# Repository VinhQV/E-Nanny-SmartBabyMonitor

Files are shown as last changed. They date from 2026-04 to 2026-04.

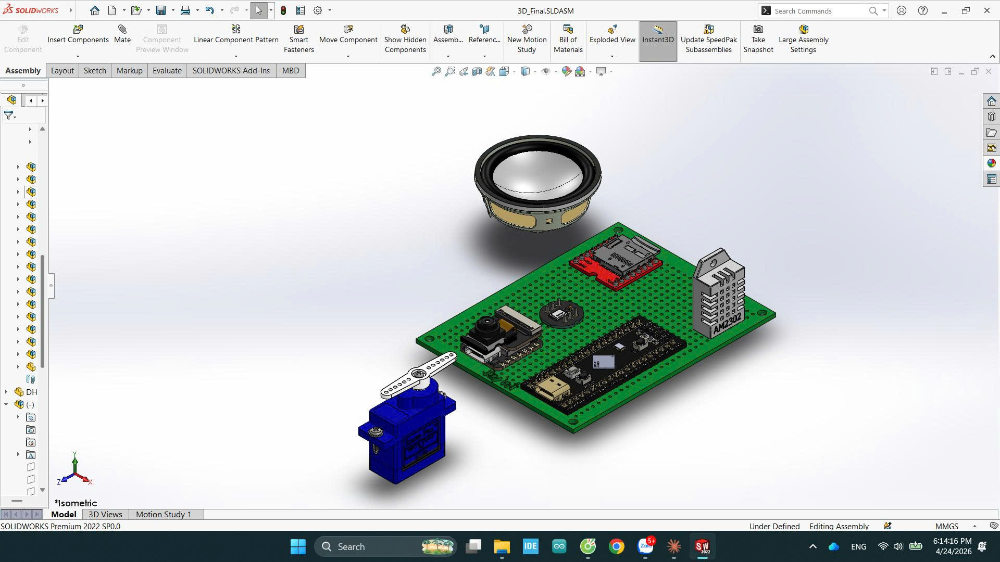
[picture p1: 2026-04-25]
media/images/hardware/3dBoardjpg.jpg

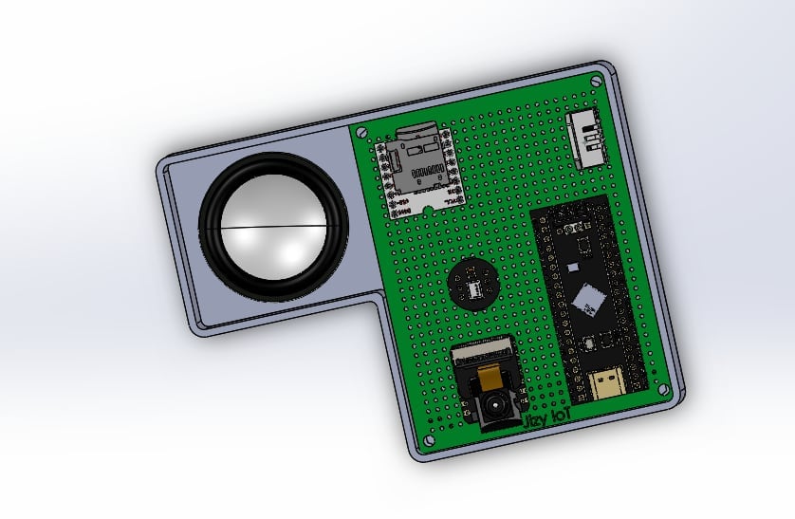
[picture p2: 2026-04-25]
media/images/hardware/fullLinhKien.jpg

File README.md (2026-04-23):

<div align="center">

# 🍼 E-Nanny: Smart Baby Monitor

**An intelligent IoT baby monitoring system built with STM32F401 + ESP32S3**







> A real-time embedded system that **detects baby crying using on-device AI**, monitors environment, soothes the baby automatically with lullabies and cradle rocking — all viewable from a live IoT dashboard.

---

System Demo
<!-- Replace with your actual demo photo/GIF -->

</div>

---

## ✨ Features

- 🤖 **On-Device AI Cry Detection** — TinyML model running on ESP32S3, classifies baby cry in real-time without sending audio to the cloud
- 📷 **Live Camera Feed** — OV2640 camera streams video via ESP32S3 for remote monitoring
- 🌡️ **Environment Sensing** — DHT22 measures temperature & humidity inside the cradle
- 🎵 **Auto Lullaby Playback** — DFPlayer Mini plays soothing music when crying is detected
- 🔄 **Cradle Auto-Rocking** — Servo SG90 gently rocks the cradle in response to baby state
- 📊 **IoT Dashboard** — ThingsBoard dashboard displays real-time sensor data & baby status
- ⚡ **Non-blocking Firmware** — STM32 firmware uses HAL_GetTick() + State Machine (no HAL_Delay)
- 🔗 **Dual-MCU Architecture** — STM32 handles real-time peripherals; ESP32S3 handles AI + networking

---

## 🏗️ System Architecture

```
┌─────────────────────────────────┐         ┌──────────────────────────────────────┐
│     STM32F401CCU6 (Core MCU)    │         │        ESP32S3 (IoT Gateway)         │
│                                 │         │                                      │
│  ┌──────────┐  ┌─────────────┐  │  UART   │  ┌──────────┐   ┌────────────────┐  │
│  │  DHT22   │  │ DFPlayer    │  │◄───────►│  │ AI Engine│   │ Camera Module  │  │
│  │ Temp/Hum │  │ (Lullaby)   │  │         │  │(Cry Detect│   │ (OV2640)       │  │
│  └──────────┘  └─────────────┘  │         │  └──────────┘   └────────────────┘  │
│                                 │         │                                      │
│  ┌──────────┐  ┌─────────────┐  │         │  ┌──────────┐   ┌────────────────┐  │
│  │ Servo    │  │  State      │  │         │  │ Audio    │   │ Cloud Client   │  │
│  │ SG90     │  │  Machine    │  │         │  │ Mic      │   │ (MQTT/WiFi)    │  │
│  │(Rocking) │  │ (Non-block) │  │         │  └──────────┘   └───────┬────────┘  │
│  └──────────┘  └─────────────┘  │         │                         │           │
└─────────────────────────────────┘         └─────────────────────────┼───────────┘
                                                                       │ MQTT
                                                                       ▼
                                                          ┌────────────────────┐
                                                          │   ThingsBoard IoT  │
                                                          │   Cloud Dashboard  │
                                                          │  (Temp/Hum/Status) │
                                                          └────────────────────┘
```

### Communication Protocol (STM32 ↔ ESP32)

| From | To | Protocol | Data |
|---|----|---|---|
| STM32 | ESP32S3 | UART 115200 baud | Temperature, Humidity (framed packet) |
| ESP32S3 | STM32 | UART 115200 baud | Commands: play music (0x01), rock cradle (0x04) |
| ESP32S3 | ThingsBoard | MQTT over WiFi | Telemetry + Baby Status string |
| ESP32S3 | OV2640 | DVP + I2C | Camera frame capture |

---

## 📦 Hardware Bill of Materials

| Component | Role | Interface | Notes |
|---|---|---|---|
| STM32F401CCU6 | Main MCU | — | ARM Cortex-M4, 84 MHz, 256KB Flash |
| Seeed XIAO ESP32S3 Sense | AI + IoT Gateway | UART | Built-in OV2640 camera + INMP441 mic |
| DHT22 (AM2302) | Temp & Humidity Sensor | 1-Wire GPIO | ±0.5°C / ±2% RH accuracy |
| DFPlayer Mini | MP3/WAV Player | UART 9600 baud | MicroSD card, 3.2W amplifier |
| Servo SG90 | Cradle Rocking Motor | PWM (TIM) | 4.8–6V, 180° rotation |

---

## 📁 Project Structure

```
E-Nanny-SmartBabyMonitor/
│
├── 📁 stm32-firmware/              # STM32CubeIDE Project (STM32F401CCU6)
│   └── Core/
│       ├── App/
│       │   ├── ChuongTrinhChinh.c  # Main application loop (non-blocking)
│       │   └── Libraries/
│       │       ├── DHT22/          # DHT22 driver (HAL_GetTick based)
│       │       └── DFPlayer/       # DFPlayer Mini UART driver
│       └── Src/
│           └── main.c              # HAL init + peripheral config (CubeMX generated)
│
├── 📁 esp32-firmware/              # PlatformIO Project (ESP32S3)
│   └── src/
│       ├── main.cpp                # Setup + main loop
│       ├── AiEngine.cpp/h          # TinyML cry detection inference
│       ├── AudioMic.cpp/h          # I2S microphone sampling (INMP441)
│       ├── CameraModule.cpp/h      # OV2640 init + frame capture
│       ├── CloudClient.cpp/h       # WiFi + MQTT (ThingsBoard)
│       └── Stm32Controller.cpp/h   # UART bridge to STM32
│
└── 📁 docs/
    ├── images/                     # Photos, screenshots, demo GIF
    └── hardware/                   # Wiring diagrams
```

---

## 🔧 Getting Started

### Prerequisites

**STM32 Firmware:**
- [STM32CubeIDE](https://www.st.com/en/development-tools/stm32cubeide.html) v1.13+
- ST-Link V2 programmer

**ESP32S3 Firmware:**
- [Visual Studio Code](https://code.visualstudio.com/) + [PlatformIO](https://platformio.org/) extension

### 1. Clone the Repository

```bash
git clone https://github.com/YOUR_USERNAME/E-Nanny-SmartBabyMonitor.git
cd E-Nanny-SmartBabyMonitor
```

### 2. Configure WiFi & ThingsBoard credentials

Edit `esp32-firmware/src/CloudClient.cpp`:

```cpp
const char* ssid     = "YOUR_WIFI_SSID";
const char* password = "YOUR_WIFI_PASSWORD";
const char* tb_token = "YOUR_THINGSBOARD_DEVICE_TOKEN";
```

> ⚠️ **Never commit real credentials to Git!** Use a `secrets.h` file that is listed in `.gitignore`.

### 3. Flash STM32 Firmware

1. Open `stm32-firmware/` folder in **STM32CubeIDE**
2. Connect ST-Link V2 to the STM32F401CCU6 board
3. `Project → Build All` → `Run → Debug`

### 4. Flash ESP32S3 Firmware

```bash
cd esp32-firmware
pio run --target upload
pio device monitor   # View serial output at 115200 baud
```

---

## 💡 Software Design Highlights

### Non-Blocking STM32 Architecture
The STM32 firmware uses a **State Machine + HAL_GetTick()** pattern — no `HAL_Delay()` blocking calls anywhere. All sensors and actuators are handled concurrently in a cooperative scheduling loop:

```c
void ChuongTrinh_Loop(void) {
    DHT22_Task();      // Non-blocking: reads every 2000ms
    DFPlayer_Task();   // Non-blocking: manages play state
    Servo_Task();      // Non-blocking: PWM rocking pattern
    UART_RxTask();     // Non-blocking: state machine parser
}
```

### UART Framed Protocol (STM32 ↔ ESP32)
Commands use a fixed-format frame to prevent packet loss/corruption:
```
[0xAA] [CMD] [DATA] [CHECKSUM]
```

### On-Device AI — No Cloud Audio
The baby cry classifier runs **entirely on the ESP32S3 edge device** using TinyML. Raw PCM audio from the I2S microphone is windowed, feature-extracted, and fed into a neural network locally — ensuring **< 500ms latency** and **zero audio data leaving the device**.

---

## 📸 Demo & Screenshots

| ThingsBoard Dashboard | Hardware Assembly |
|---|---|
| Dashboard | Hardware |

> 📹 Demo video: [Watch on YouTube](https://youtube.com/YOUR_VIDEO_LINK)

---

## 🗺️ Roadmap

- [x] DHT22 temperature & humidity sensing
- [x] DFPlayer Mini lullaby auto-playback
- [x] Servo SG90 cradle auto-rocking
- [x] Baby cry detection (TinyML on ESP32S3)
- [x] ThingsBoard MQTT IoT dashboard
- [x] OV2640 live camera feed
- [ ] Mobile push notifications (React Native)
- [ ] OTA firmware update for ESP32S3
- [ ] Improved AI model (larger dataset, better accuracy)

---

## 📄 License

This project is licensed under the MIT License — see [LICENSE](LICENSE) for details.

---

## 👤 Author

**Vinh Gia Vi**
- GitHub: [@YOUR_USERNAME](https://github.com/YOUR_USERNAME)
- Email: voquangvinh.ptit@gmail.com
- University: Posts and Telecommunications Institute of Technology (PTIT)

---

<div align="center">

⭐ If you find this project useful or interesting, a star would mean a lot! ⭐

</div>

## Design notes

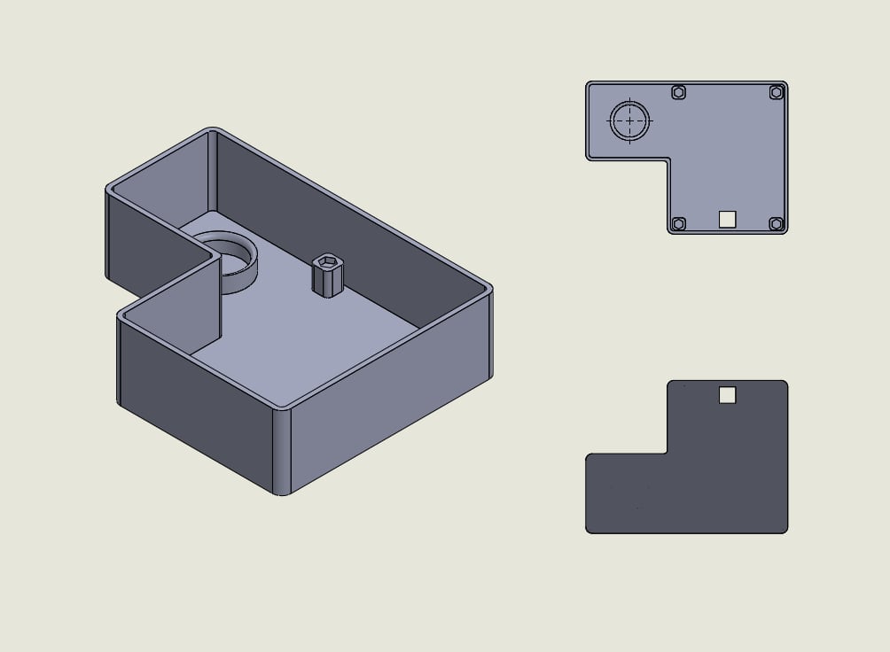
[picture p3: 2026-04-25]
media/images/hardware/naphop.jpg

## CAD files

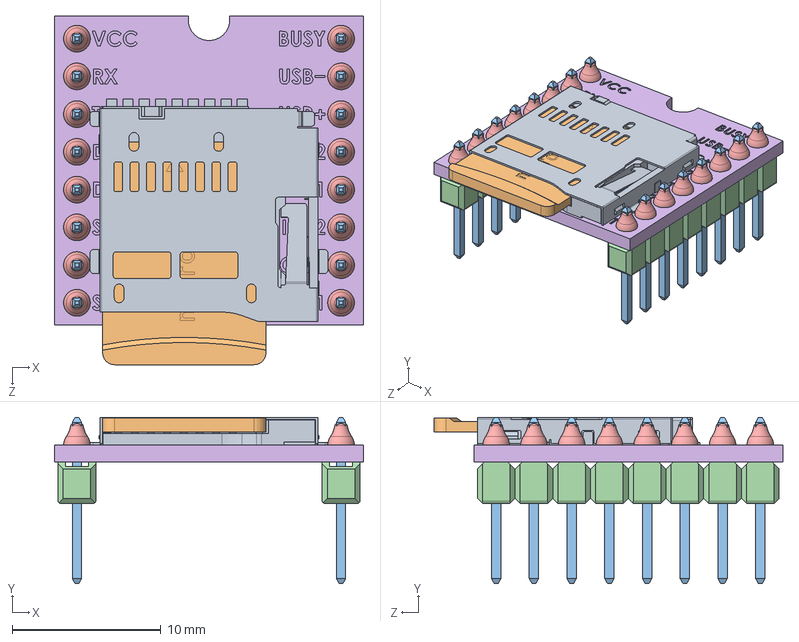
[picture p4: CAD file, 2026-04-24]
solidWorks/3dBoard/DFPlayer Mini Assem v1.step.SLDASM
20.8 x 11.2 x 23.5 mm
CD card slot^SD card Assem_DFPlayer Mini Assem v1.step
Micro sd card^SD card Assem_DFPlayer Mini Assem v1.step
11_20mm pin.step x 16
Pin Header 1x12 TH Pitch 2.step x 16
solder.step x 16
DFPlayer Mini PCB^DFPlayer Mini Assem v1.step

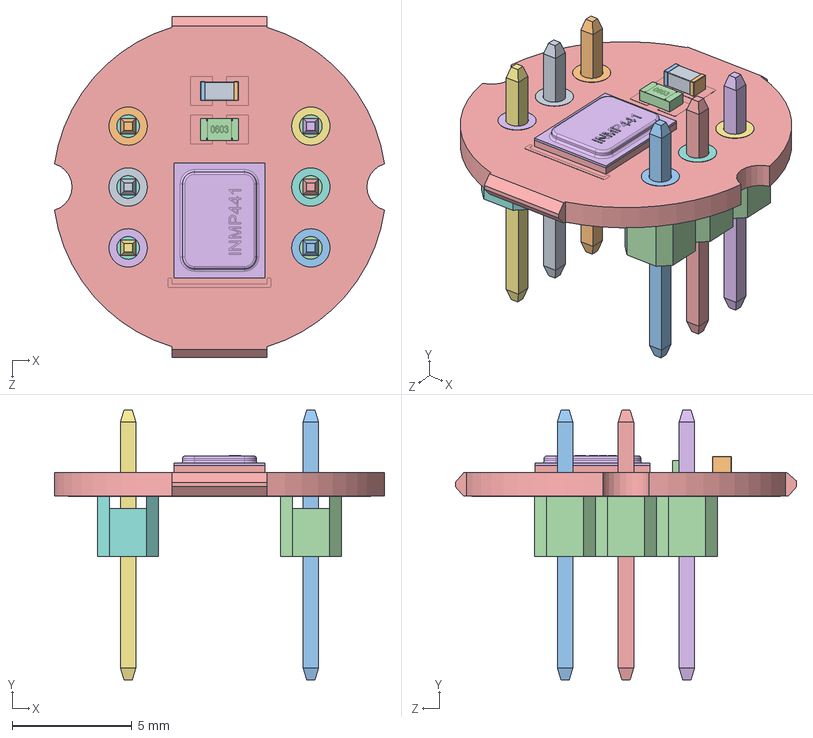
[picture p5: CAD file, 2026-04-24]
solidWorks/3dBoard/INMP441 I2S Microphone Module v15.SLDASM
13.8 x 11.2 x 14.2 mm
Part 3.step
Part 2.step
Part 1.step
0603 Resistor.step
INMP441 I2S Microphone Module.step
INMP441 I2S Microphone Module-0.step
INMP441 I2S Microphone Module-1.step
INMP441 I2S Microphone Module-2.step
INMP441 I2S Microphone Module-3.step
INMP441 I2S Microphone Module-4.step
INMP441 I2S Microphone Module-5.step
INMP441 I2S Microphone Module-6.step
INMP441 I2S Microphone Module-7.step
INMP441 I2S Microphone Module-8.step
INMP441 I2S Microphone Module-9.step
INMP441 I2S Microphone Module-10.step
INMP441 I2S Microphone Module-11.step
INMP441 I2S Microphone Module-12.step
INMP441 I2S Microphone Module-13.step
INMP441 I2S Microphone Module-14.step
INMP441 I2S Microphone Module-15.step
INMP441 I2S Microphone Module-16.step

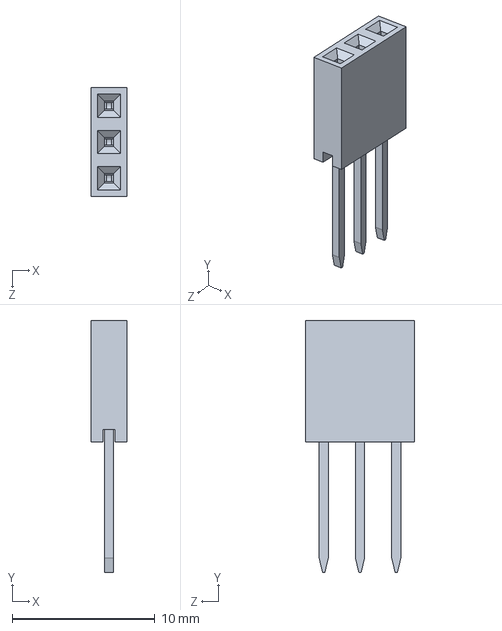
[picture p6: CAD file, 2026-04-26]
solidWorks/3dBoard/pin header female 2.54mm_0.1in.SLDPRT
2.54 x 17.6 x 7.62 mm

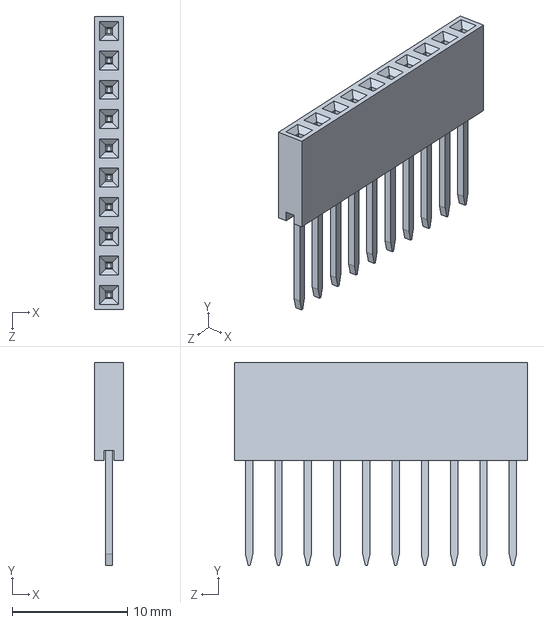
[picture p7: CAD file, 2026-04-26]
solidWorks/3dBoard/1x10.SLDPRT
2.54 x 17.6 x 25.4 mm

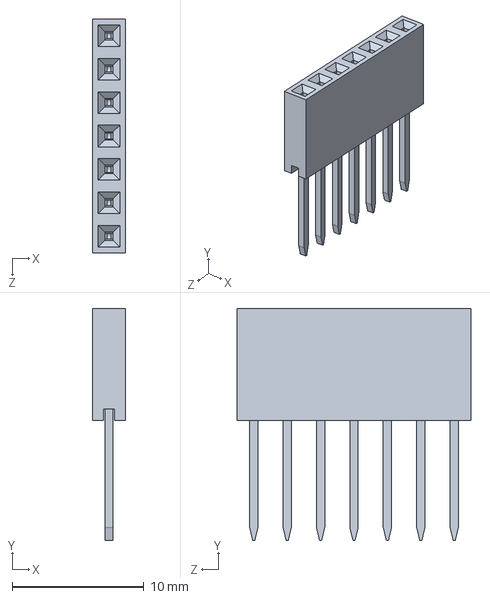
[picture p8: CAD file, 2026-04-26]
solidWorks/3dBoard/1x7.SLDPRT
2.54 x 17.6 x 17.8 mm

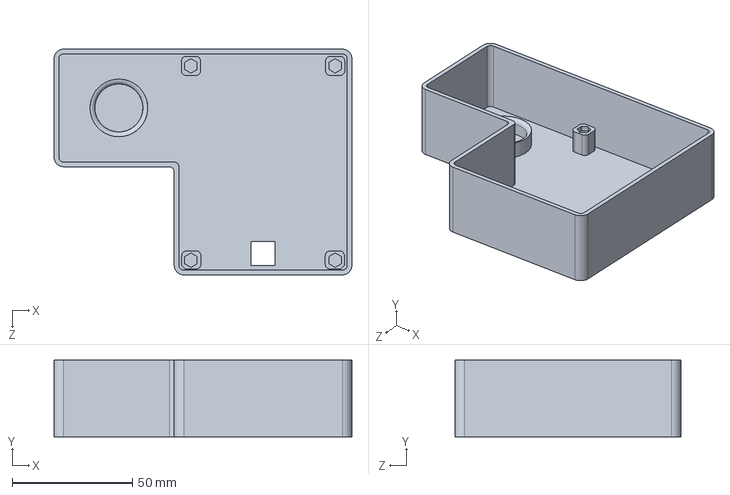
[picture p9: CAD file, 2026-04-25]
solidWorks/3dBoard/DeHop7x9.SLDPRT
124.0 x 32.0 x 94.0 mm

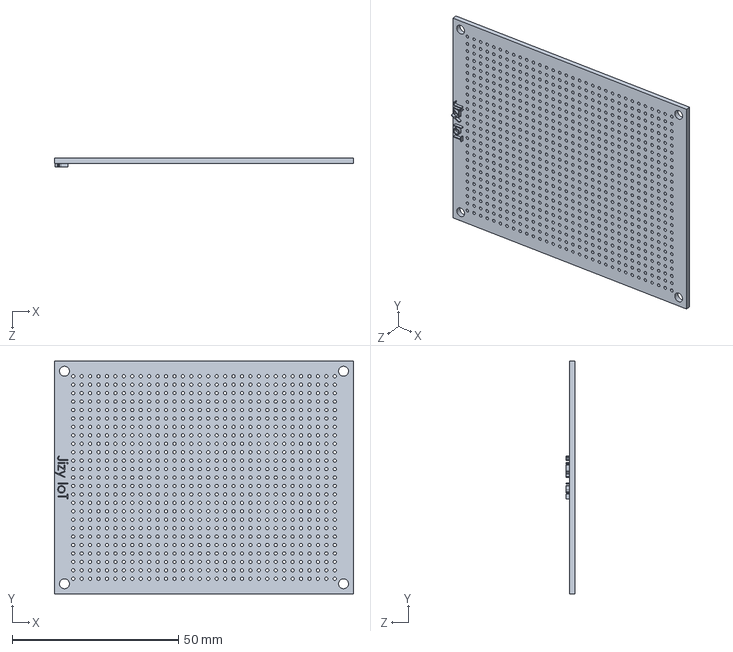
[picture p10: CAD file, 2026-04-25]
solidWorks/3dBoard/BoardDong7x9.SLDPRT
90.0 x 70.0 x 2.60 mm

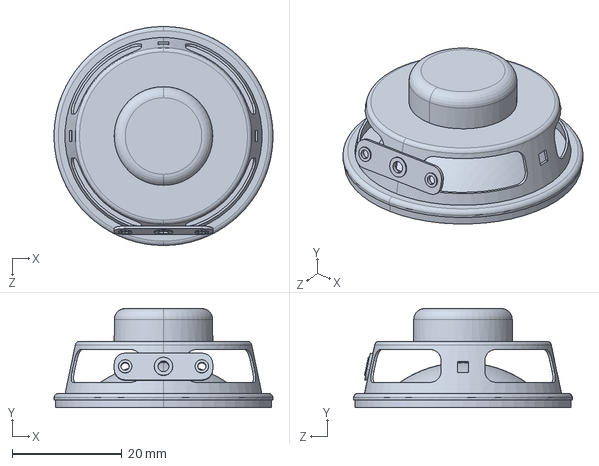
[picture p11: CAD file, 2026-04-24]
solidWorks/3dBoard/SPEAKER 4OHM 3W.step.SLDPRT
40.0 x 18.1 x 40.0 mm

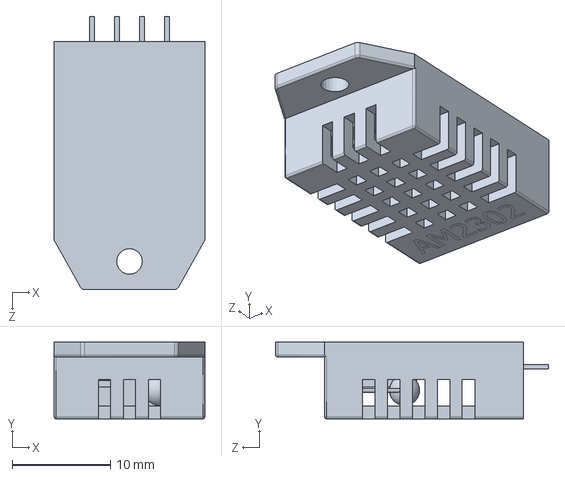
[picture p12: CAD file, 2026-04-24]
solidWorks/3dBoard/DHT22.SLDPRT
15.3 x 7.80 x 27.7 mm

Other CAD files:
solidWorks/3dBoard/SG90 - Micro Servo 9g - Tower Pro.SLDASM
solidWorks/3dBoard/DFPlayer Mini Pin.step.SLDASM
solidWorks/3dBoard/Pin Header 1x12 TH Pitch 2.step.SLDPRT
solidWorks/3dBoard/solder.step.SLDPRT
solidWorks/3dBoard/11_20mm pin.step.SLDPRT
solidWorks/3dBoard/1x20 Male Pin Header.STEP.SLDPRT
solidWorks/3dBoard/DeHop7x9.SLDDRW

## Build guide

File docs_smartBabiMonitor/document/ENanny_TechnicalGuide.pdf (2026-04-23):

# TÀI LIỆU KỸ THUẬT CHUYÊN SÂU

MỤC LỤC

1. Chương 1 — Giới thiệu hệ thống: Sơ đồ khối và nguyên lý hoạt động
2. Chương 2 — Cấu hình phần cứng: Pinout, Timer và tài nguyên UART
3. Chương 3 — Phân tích Driver chi tiết (DHT22 & DFPlayer)
4. Chương 4 — Tư duy lập trình hệ thống: State Machine và Non-blocking
5. Chương 5 — Hướng dẫn cài đặt, chạy thực tế và debug

# CHƯƠNG 1 — GIỚI THIỆU HỆ THỐNG

## 1.1. Tổng quan dự án

E-Nanny (Smart Baby Monitor) là một hệ thống giám sát và chăm sóc trẻ sơ sinh từ xa. Thiết bị thực hiện bốn nhóm chức năng chính: đo nhiệt độ và độ ẩm môi trường, rung nôi tự động với biên độ an toàn, phát nhạc ru theo yêu cầu, và truyền dữ liệu lên ứng dụng di động thông qua kết nối WiFi/MQTT do ESP32 đảm nhiệm.
Kiến trúc phần cứng chia trách nhiệm rất rõ ràng: STM32F401CCU6 chịu trách nhiệm về phần thời gian thực (real-time) — điều khiển servo rung nôi, đọc cảm biến, giao tiếp với module MP3 — trong khi ESP32 đảm nhiệm kết nối Internet và giao diện với người dùng. Hai vi điều khiển trao đổi dữ liệu qua một đường UART duy nhất sử dụng khung truyền tự thiết kế.
1.2. Sơ đồ khối hệ thống Dự án: E-Nanny – Smart Baby Monitor Kiến trúc: STM32F401CCU6 (MCU chính) + ESP32 (IoT Gateway) Phiên bản: 1.0 — Biên soạn cho người mới bắt đầu Phạm vi: Phân tích code, thiết kế module, giao thức truyền thông và quy trình triển khai

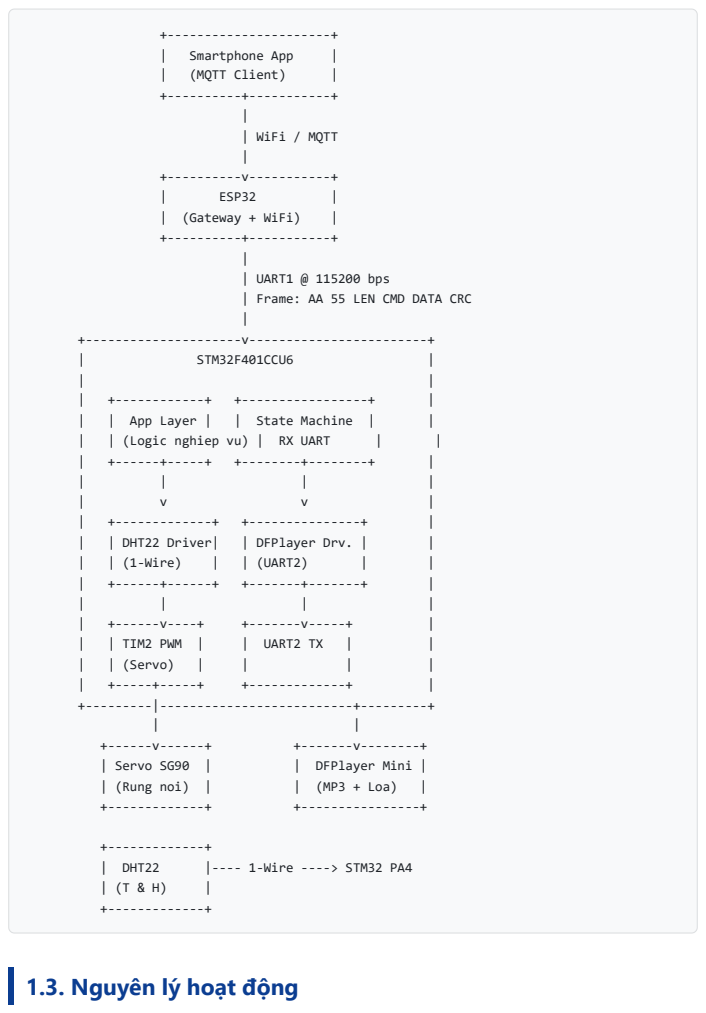
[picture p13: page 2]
Smartphone App; (MQTT Client); +----------+-----------+ | | WiFi / MQTT | +----------v-----------+; ESP32; | (Gateway + WiFi); STM32F401CCU6; | App Layer |; | State Machine |; | (Logic nghiep vu) | RX UART; | DHT22 Driver|; | DFPlayer Drv. |; | (1-Wire); | (UART2); | TIM2 PWM |; | UART2 TX; | (Servo); | Servo SG90 |; | DFPlayer Mini |; | (Rung noi) |; | (MP3 + Loa); | DHT22; |---- 1-Wire ----> STM32 PA4

UART1 @ 115200 bps
Frame: AA 55 LEN CMD DATA CRC

1.3. Nguyên lý hoạt động

Hệ thống hoạt động theo mô hình super-loop non-blocking — vòng lặp chính của STM32 liên tục quét ba nhóm công việc, nhưng mỗi nhóm đều tự quản lý thời gian của mình để không bao giờ chặn các nhóm còn lại. Cụ thể:
Nhóm 1 — Đọc cảm biến môi trường. Cứ mỗi 2 giây, STM32 kích hoạt driver DHT22 để lấy một mẫu nhiệt độ và độ ẩm. Sau khi đọc thành công, dữ liệu được đóng gói vào frame có CRC và gửi qua UART1 sang ESP32. ESP32 tiếp tục đẩy lên cloud thông qua MQTT.
Nhóm 2 — Nhận lệnh điều khiển từ ESP32. Khi người dùng bấm nút trên ứng dụng (ví dụ "Rung nôi", "Phát nhạc ru số 3"), ESP32 đóng gói thành frame và gửi xuống STM32. STM32 nhận từng byte bằng ngắt UART, ghép frame qua máy trạng thái, kiểm tra CRC, rồi thực thi lệnh ở vòng lặp chính.
Nhóm 3 — Điều khiển thiết bị ngoại vi. Khi có lệnh rung nôi, cờ is_rocking được bật và hàm Servo_Rocking_Task() sẽ tự động quay qua lại giữa hai góc 60° và 120° với bước 1° mỗi 20ms — không cần bất kỳ delay nào. Khi có lệnh phát nhạc, driver DFPlayer sẽ gửi lệnh điều khiển qua UART2 tới module MP3.

Điểm then chốt của thiết kế: Ba nhóm trên không phải chạy tuần tự (xong cái này mới tới cái kia). Nhờ cơ chế HAL_GetTick() kết hợp với ngắt UART, cả ba luôn trong trạng thái "hoạt động đồng thời" ở góc nhìn của người dùng.

# CHƯƠNG 2 — CẤU HÌNH PHẦN CỨNG

## 2.1. Bảng chân (Pinout) của STM32F401CCU6

Toàn bộ pinout của dự án được tổng hợp trong bảng dưới đây. Đây là phần bắt buộc phải tuân thủ khi đấu nối phần cứng để không phải sửa lại firmware.

Chân STM32 | Chức năng | Chế độ (Mode) | Kết nối tới | Ghi chú
PA4 | DHT22 Data | GPIO Output Push-Pull / Input (chuyển runtime) | Chân DATA của DHT22 | Cần điện trở kéo lên 4.7kΩ lên VCC

Chân STM32 | Chức năng | Chế độ (Mode) | Kết nối tới | Ghi chú
PA0 | TIM2_CH1 (PWM) | Alternate Function PP | Chân tín hiệu Servo SG90 | PWM 50Hz, độ rộng xung 0.5ms–2.5ms
PA9 | USART1_TX | Alternate Function | RX của ESP32 | 115200-8-N-1
PA10 | USART1_RX | Alternate Function (có Pull-up) | TX của ESP32 | Bật NVIC interrupt
PA2 | USART2_TX | Alternate Function | RX của DFPlayer Mini | 9600-8-N-1
PA3 | USART2_RX | Alternate Function | TX của DFPlayer Mini | Dùng để đọc phản hồi (tuỳ chọn)
PA13 / PA14 | SWDIO / SWCLK | Serial Wire Debug | ST-Link hoặc J-Link | Không được dùng cho mục đích khác
3V3 / GND | Nguồn | — | Toàn hệ thống | DHT22 và Servo dùng 5V (qua module nguồn riêng)

## 2.2. Bảng tài nguyên Timer

Hai Timer được huy động cho hai mục đích hoàn toàn khác nhau. Đây là lý do phải chọn Timer có nguồn clock phù hợp trên từng bus APB.

Timer | Bus | Prescaler | Period (ARR) | Mode | Dùng cho | Giải thích tính toán
TIM2 | APB1 (48 MHz sau ×2) | 47 | 19999 | PWM Generation CH1 | Servo SG90 (rung nôi) | 48MHz / (47+1) = 1MHz tick. Period 20000 → chu kỳ 20ms = 50Hz (chuẩn servo)

Timer | Bus | Prescaler | Period (ARR) | Mode | Dùng cho | Giải thích tính toán
TIM11 | APB2 (84 MHz) | 83 | 65535 | Base Counter | Tạo delay chính xác theo µs cho DHT22 | 84MHz / (83+1) = 1MHz tick → 1 tick = 1µs

Nguyên tắc chọn Prescaler: Công thức chuẩn là Prescaler = (ClockBus / TickMongMuon) - 1 . Với TIM11 ta muốn tick 1µs trên bus 84MHz nên Prescaler = 84 - 1 =
83. Với TIM2 ta muốn tick 1µs trên bus 48MHz hiệu dụng nên Prescaler = 48 - 1 = 47.

## 2.3. Bảng tài nguyên UART

Ngoại vi | Baudrate | Word Length | Parity | Stop Bit | Chế độ | Mục đích
USART1 | 115200 | 8 bit | None | 1 | Interrupt RX, Polling TX | Giao tiếp với ESP32
USART2 | 9600 | 8 bit | None | 1 | Polling TX | Gửi lệnh cho DFPlayer Mini

## 2.4. Cấu trúc thư mục source code

Dự án được tổ chức theo kiến trúc phân tầng rõ ràng. Đây là cấu trúc bắt buộc để đảm bảo tính module hoá và tái sử dụng.

STM32_SmartBabyMonitor/
+-- Core/
| | +-- Inc/ | (Header he thong - CubeMX tu sinh)
| | | | +-- main.h
| | | | +-- stm32f4xx_hal_conf.h
| | +-- Src/ | (Source he thong - CubeMX tu sinh)
| | | | +-- main.c | (Chi goi Init va Loop cua App)
| | | | +-- system_stm32f4xx.c
| | +-- App/ | (Tu viet - tang ung dung)
| | | +-- ChuongTrinhChinh.c | (Dieu phoi task, state machine UART)

| | +-- ChuongTrinhChinh.h
| | +-- Libraries/
| | +-- DHT22/
| | | | +-- DHT22.c | (Driver 1-Wire cho cam bien)
| | | | +-- DHT22.h
| | +-- DFPlayer/
| | | +-- DFPlayer.c | (Driver giao thuc 10 byte)
| | | +-- DFPlayer.h
+-- Drivers/ | | | (HAL + CMSIS cua ST)

# CHƯƠNG 3 — PHÂN TÍCH DRIVER CHI TIẾT

## 3.1. Driver DHT22 — Phân tích từng hàm

### 3.1.1. Tại sao phải đổi chiều chân GPIO (Input ⇄ Output)?

DHT22 sử dụng giao thức 1-Wire tự chế — chỉ dùng duy nhất một sợi dây tín hiệu cho cả việc MCU gửi lệnh "đánh thức" và việc DHT22 trả dữ liệu. Do đó, tại mỗi thời điểm, chỉ một bên được phép lái (drive) đường tín hiệu. Nếu cả hai cùng lái và một bên đẩy HIGH trong khi bên kia kéo LOW, sẽ xảy ra chập ngắn mạch cục bộ gây cháy GPIO.
Giải pháp: MCU phải chủ động chuyển chân PA4 sang chế độ Output Push-Pull khi cần gửi tín hiệu START (kéo LOW 1.2ms rồi HIGH 20µs), sau đó chuyển về chế độ Input (kèm pull-up ngoài) để "nghe" DHT22 trả lời.

// DHT22.c - Ham phu tro chuyen che do chan GPIO

static void Set_Pin_Output(GPIO_TypeDef *GPIOx, uint16_t GPIO_Pin) {
GPIO_InitTypeDef GPIO_InitStruct = {0};
GPIO_InitStruct.Pin = GPIO_Pin;
GPIO_InitStruct.Mode = GPIO_MODE_OUTPUT_PP; // Push-Pull de lai duoc ca HIGH va L GPIO_InitStruct.Pull = GPIO_NOPULL;
GPIO_InitStruct.Speed = GPIO_SPEED_FREQ_LOW;
HAL_GPIO_Init(GPIOx, &GPIO_InitStruct);
}

static void Set_Pin_Input(GPIO_TypeDef *GPIOx, uint16_t GPIO_Pin) {

GPIO_InitTypeDef GPIO_InitStruct = {0};
GPIO_InitStruct.Pin = GPIO_Pin;
GPIO_InitStruct.Mode = GPIO_MODE_INPUT; | // Tha chan de chi "nghe"
GPIO_InitStruct.Pull = GPIO_NOPULL; | // Dien tro keo len o ben ngoai (4.7k
HAL_GPIO_Init(GPIOx, &GPIO_InitStruct);
}

### 3.1.2. Tại sao phải dùng Timer (TIM11) thay vì HAL_Delay()?

Hàm | Độ phân giải | Vấn đề
HAL_Delay(ms) | 1 mili giây | DHT22 yêu cầu chính xác 40µs, 80µs — sai số quá lớn
Vòng for trống | Không xác định | Trình biên dịch tối ưu có thể xoá vòng lặp
TIM11 counter | 1 µs | Chính xác, không phụ thuộc optimization level

// DHT22.c - Ham delay chinh xac toi microsecond
extern TIM_HandleTypeDef htim11;

static void delay_us(uint16_t us) {
__HAL_TIM_SET_COUNTER(&htim11, 0); | // Reset bo dem ve 0
while (__HAL_TIM_GET_COUNTER(&htim11) < us); | // Doi den khi dem du us tick
}

Lưu ý bắt buộc: Trong ChuongTrinh_Init() , phải gọi HAL_TIM_Base_Start(&htim11);
để kích hoạt bộ đếm trước khi bất kỳ hàm nào trong driver DHT22 được dùng. Bỏ qua bước này là nguyên nhân phổ biến nhất khiến driver "tưởng là đúng mà luôn đọc lỗi".

### 3.1.3. Giao thức 1-Wire của DHT22

MCU keo LOW 1.2ms | MCU keo HIGH 20us | MCU chuyen sang INPUT
+--------+ | +-----+ | +----->
____| | |___________| | |__________________|
v | v
Start | Release
DHT22 tra loi:
+-- 80us LOW (ACK) --+-- 80us HIGH (ACK) --+

Phân biệt bit 0 và bit 1: Mỗi bit bắt đầu bằng một xung LOW 50µs. Sau đó:
Nếu xung HIGH kéo dài ~26µs → đó là bit 0 (xung ngắn)
Nếu xung HIGH kéo dài ~70µs → đó là bit 1 (xung dài)

Thủ thuật đọc: sau cạnh lên, đợi đúng 40µs rồi đọc mức logic. Nếu đã LOW thì xung HIGH ngắn hơn 40µs → bit 0. Nếu vẫn HIGH thì xung HIGH dài hơn 40µs → bit 1.

### 3.1.4. Hàm DHT22_Start() — Giải phẫu từng dòng

static uint8_t DHT22_Start(void) {
uint8_t response = 0;
uint8_t timeout = 0;

// Buoc 1: MCU lai chan, keo LOW 1.2ms de danh thuc DHT22
// Chuan chinh thuc: >= 1ms. Ta chon 1.2ms de co bien an toan. Set_Pin_Output(DHT_PORT, DHT_PIN);
HAL_GPIO_WritePin(DHT_PORT, DHT_PIN, GPIO_PIN_RESET); delay_us(1200);

// Buoc 2: MCU keo HIGH 20us de ra hieu "da xong start" HAL_GPIO_WritePin(DHT_PORT, DHT_PIN, GPIO_PIN_SET);
delay_us(20);

// Buoc 3: Chuyen chan sang INPUT - tha quyen dieu khien cho DHT22 // Tu day MCU chi doc, khong duoc ghi nua Set_Pin_Input(DHT_PORT, DHT_PIN);
delay_us(40);

// Buoc 4: Kiem tra xung ACK cua DHT22
// | DHT22 phai keo LOW 80us, roi HIGH 80us
if (!(HAL_GPIO_ReadPin(DHT_PORT, DHT_PIN))) { | // Dang LOW
delay_us(80);
if ((HAL_GPIO_ReadPin(DHT_PORT, DHT_PIN))) { | // Da chuyen HIGH
response = 1; | // ACK hop le
}
}

// Cho het xung HIGH cuoi cua ACK (truoc khi bit du lieu dau tien toi) // Co timeout de khong treo may neu cam bien hong
while ((HAL_GPIO_ReadPin(DHT_PORT, DHT_PIN))) {

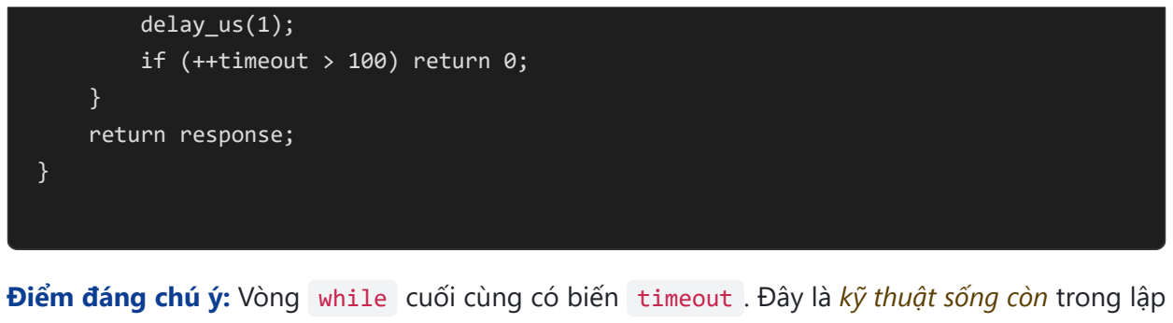
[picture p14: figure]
delay_us(1); if (++timeout > 100) return 0;; } return response;

Điểm đáng chú ý: Vòng while cuối cùng có biến timeout . Đây là kỹ thuật sống còn trong lập trình embedded — không bao giờ được có vòng lặp chờ tín hiệu mà không có điều kiện thoát. Nếu DHT22 bị hỏng phần cứng, chân luôn ở HIGH thì vòng while sẽ chạy mãi và treo hệ thống.

### 3.1.5. Hàm DHT22_Read_Byte()

static uint8_t DHT22_Read_Byte(void) { uint8_t i = 0;
uint16_t timeout;

// Doc 8 bit theo thu tu MSB first
for (uint8_t j = 0; j < 8; j++) {

// 1. Doi het phan LOW 50us dau moi bit
timeout = 0;
while (!(HAL_GPIO_ReadPin(DHT_PORT, DHT_PIN))) { delay_us(1);
if (++timeout > 100) return 0; // Timeout chong treo }

// 2. Dang trong pha HIGH, doi dung 40us roi doc muc logic delay_us(40);

if (!(HAL_GPIO_ReadPin(DHT_PORT, DHT_PIN))) {
// Tai moc 40us ma da LOW --> xung HIGH ngan --> bit 0 i &= ~(1 << (7 - j));
} else {
// Tai moc 40us van HIGH --> xung HIGH dai --> bit 1 i |= (1 << (7 - j));

// Doi phan con lai cua xung HIGH (70-40 = 30us nua) timeout = 0;
while ((HAL_GPIO_ReadPin(DHT_PORT, DHT_PIN))) { delay_us(1);
if (++timeout > 100) return 0;
}
}

### 3.1.6. Hàm public DHT22_Read() và kiểm tra Checksum

DHT22 gửi tổng cộng 40 bit = 5 byte có cấu trúc:

Byte | Ý nghĩa
1 | Humidity HIGH (8 bit cao của độ ẩm)
2 | Humidity LOW (8 bit thấp của độ ẩm)
3 | Temperature HIGH (8 bit cao của nhiệt độ)
4 | Temperature LOW (8 bit thấp của nhiệt độ)
5 | Checksum = (byte1 + byte2 + byte3 + byte4) & 0xFF

uint8_t DHT22_Read(volatile DHT22_Data_t *DHT_Data) { uint8_t Rh_byte1, Rh_byte2, Temp_byte1, Temp_byte2; uint16_t checkSum = 0;

if (DHT22_Start() == 1) {
Rh_byte1 | = DHT22_Read_Byte();
Rh_byte2 | = DHT22_Read_Byte();
Temp_byte1 = DHT22_Read_Byte(); Temp_byte2 = DHT22_Read_Byte(); checkSum = DHT22_Read_Byte();
}

// Kiem tra tong bit - chong nhieu duong truyen
if (checkSum == ((Rh_byte1 + Rh_byte2 + Temp_byte1 + Temp_byte2) & 0xFF)) {
uint16_t raw_temp = (Temp_byte1 << 8) | Temp_byte2;
uint16_t raw_humid = (Rh_byte1 << 8) | Rh_byte2;

// DHT22 dong goi nhiet va am nhan 10 --> chia lai 10 DHT_Data->Temperature = (float)raw_temp / 10.0f;
DHT_Data->Humidity | = (float)raw_humid / 10.0f;
return 1; | // Doc thanh cong
}

return 0; | // Loi checksum --> bo qua mau nay

Triết lý "fail safe": Khi checksum sai, hàm không trả giá trị đoán mò mà trả về 0 (lỗi). App layer sẽ tự quyết định có dùng lại mẫu cũ hay không. Đây là nguyên tắc "trả đúng hoặc không trả gì cả" trong lập trình embedded.

## 3.2. Giao thức UART tự thiết kế (STM32 ⇄ ESP32)

### 3.2.1. Tại sao không gửi text thô?

Gửi chuỗi dạng "T=28.5,H=65\n" là cách đơn giản nhất, nhưng trong sản phẩm thật sự sẽ gây ra nhiều rắc rối: nếu mất một byte giữa đường (nhiễu điện từ, đứt tạm thời dây kết nối) thì sẽ không biết cách khôi phục; không phát hiện được dữ liệu bị bóp méo; và rất khó mở rộng khi muốn thêm lệnh mới.
Giải pháp chuyên nghiệp: Thiết kế một khung truyền nhị phân (binary frame) có header cố định, độ dài tường minh và mã kiểm tra lỗi.

### 3.2.2. Cấu trúc Frame

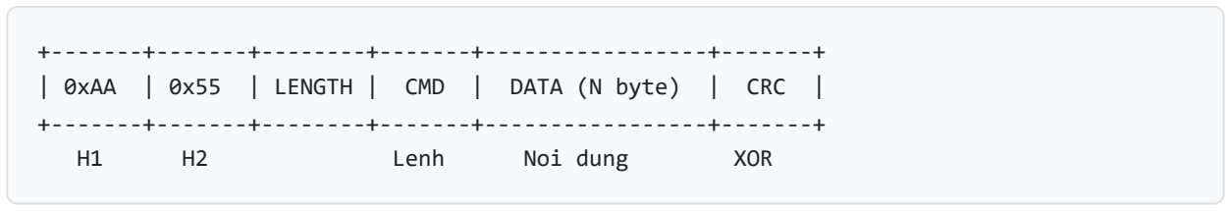
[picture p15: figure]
Lenh; Noi dung; XOR

| 0xAA | 0x55 | LENGTH | CMD | DATA (N byte) | CRC |
Trường | Kích thước | Mục đích
Header 1 (0xAA) | 1 byte | Đánh dấu bắt đầu frame
Header 2 (0x55) | 1 byte | Xác nhận kép, chống nhiễu ngẫu nhiên
Length | 1 byte | Số byte của (CMD + DATA)
CMD | 1 byte | Mã lệnh điều khiển
Data | N byte | Tham số của lệnh
CRC | 1 byte | XOR của toàn bộ (Length + CMD + Data)

### 3.2.3. Bảng lệnh giao tiếp (Protocol Table)

CMD | Hướng | Ý nghĩa | Cấu trúc Data
0x01 | ESP32 → STM32 | Phát / Dừng nhạc ru | 1 byte: 0 = Stop, 1..N = Track number
0x02 | ESP32 → STM32 | Quay servo đến góc cố định | 1 byte: 0–180 (độ)
0x03 | 2 chiều | Gửi / Yêu cầu nhiệt độ-độ ẩm | 2 byte: Temp, Humidity
0x04 | ESP32 → STM32 | Bật / Tắt rung nôi | 1 byte: 0 = Tắt, 1 = Bật

### 3.2.4. Ví dụ frame thực tế

Yêu cầu ESP32 bảo STM32 phát nhạc track số 5:

AA 55 02 01 05 06
| | | | | +-- CRC = 0x02 XOR 0x01 XOR 0x05 = 0x06
| | | | +----- Data = 0x05 (track 5)
| | | +-------- CMD = 0x01 (play)
| | +----------- LEN = 0x02 (CMD + Data)
| +-------------- H2 | = 0x55
+----------------- H1 | = 0xAA

# CHƯƠNG 4 — TƯ DUY LẬP TRÌNH HỆ THỐNG

## 4.1. Máy trạng thái (State Machine) trong ngắt UART

### 4.1.1. Vấn đề với HAL_UART_Receive() blocking

Hàm HAL_UART_Receive(&huart1, buf, 10, 1000) sẽ chặn CPU tối đa 1 giây để chờ nhận đủ
10 byte. Trong suốt 1 giây đó, servo không quay được, DHT22 không đọc được, hệ thống "đơ" hoàn toàn. Đây là anti-pattern tuyệt đối không được dùng trong firmware sản phẩm.

### 4.1.2. Giải pháp: Nhận từng byte qua ngắt + State Machine

Thay vì chờ cả frame, ta chỉ đăng ký ngắt để nhận đúng 1 byte. Mỗi khi byte đó đến, ISR sẽ chạy rất nhanh (vài µs), ghép byte đó vào buffer dựa trên trạng thái hiện tại của máy trạng thái, rồi ngay lập tức đăng ký ngắt cho byte kế tiếp. CPU gần như luôn rảnh để làm việc khác.

### 4.1.3. Sơ đồ máy trạng thái

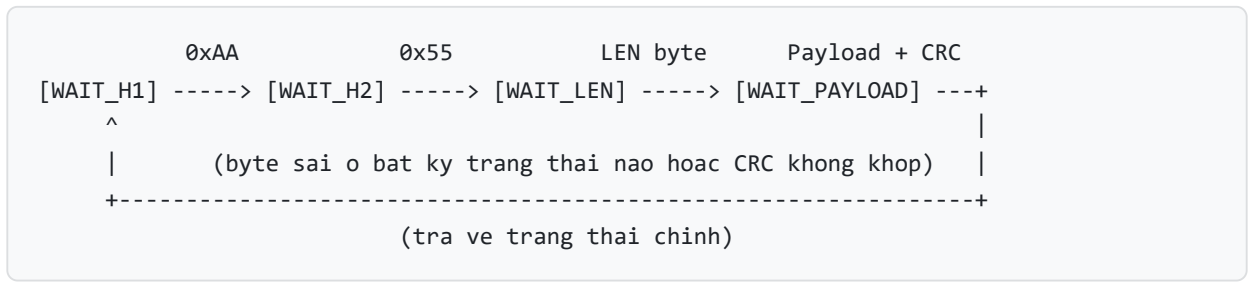
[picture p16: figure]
0xAA; LEN byte; Payload + CRC; +----------------------------------------------------------------+ (tra ve trang thai chinh)

[WAIT_H1] -----> [WAIT_H2] -----> [WAIT_LEN] -----> [WAIT_PAYLOAD] ---+

| | (byte sai o bat ky trang thai nao hoac CRC khong khop) | |

Bốn trạng thái của máy có vai trò như một "người soát vé" nhiều lớp: nếu byte đầu không phải 0xAA , không chuyển trạng thái; nếu byte thứ hai không phải 0x55 , reset về đầu; nếu Length quá lớn, reset về đầu (chống tràn buffer); cuối cùng nếu CRC không khớp, cũng reset. Bất kỳ sai lệch nào cũng đưa máy về đúng trạng thái chờ ban đầu, đảm bảo hệ thống tự đồng bộ lại khi có nhiễu.

### 4.1.4. Triển khai state machine

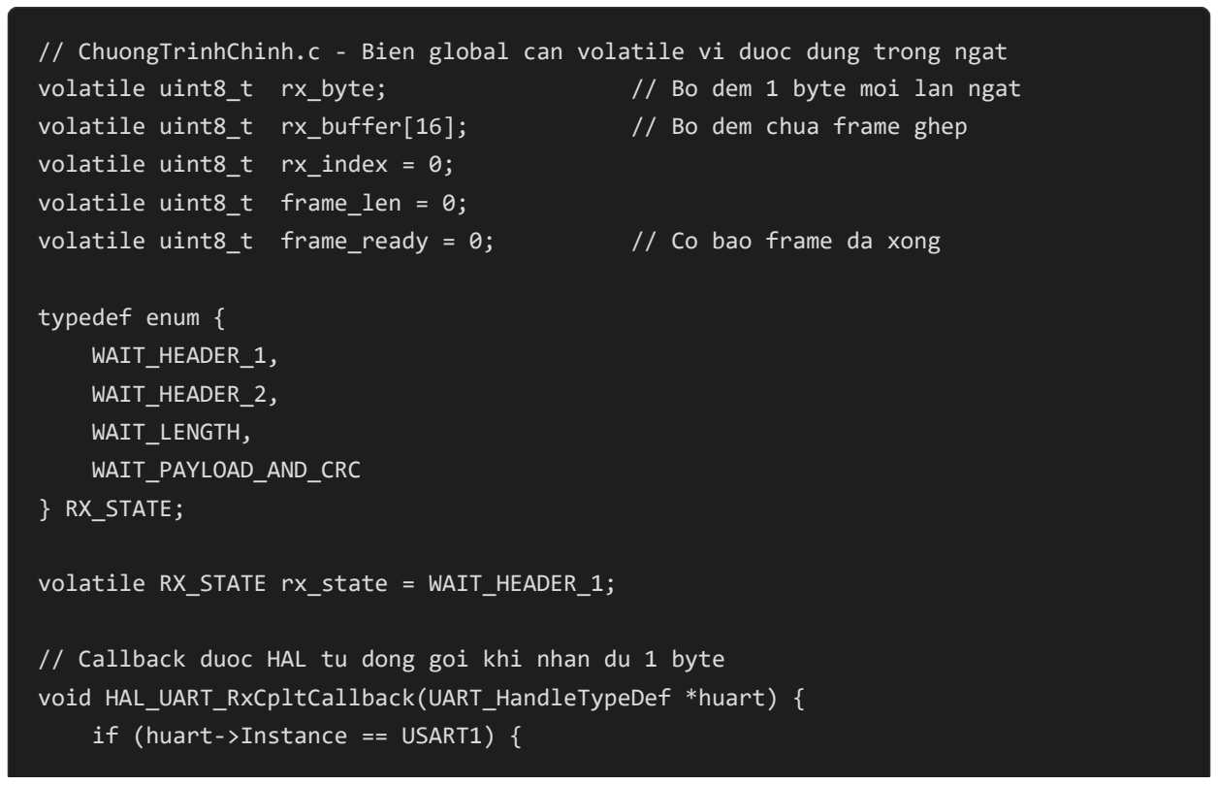
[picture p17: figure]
volatile uint8_t rx_index = 0; volatile uint8_t frame_len = 0;; typedef enum { WAIT_HEADER_1, WAIT_HEADER_2, WAIT_LENGTH, WAIT_PAYLOAD_AND_CRC } RX_STATE;; volatile RX_STATE rx_state = WAIT_HEADER_1;; void HAL_UART_RxCpltCallback(UART_HandleTypeDef *huart) { if (huart->Instance == USART1) {

// ChuongTrinhChinh.c - Bien global can volatile vi duoc dung trong ngat
volatile uint8_t rx_byte; | // Bo dem 1 byte moi lan ngat
volatile uint8_t rx_buffer[16]; | // Bo dem chua frame ghep
volatile uint8_t frame_ready = 0; | // Co bao frame da xong

// Callback duoc HAL tu dong goi khi nhan du 1 byte

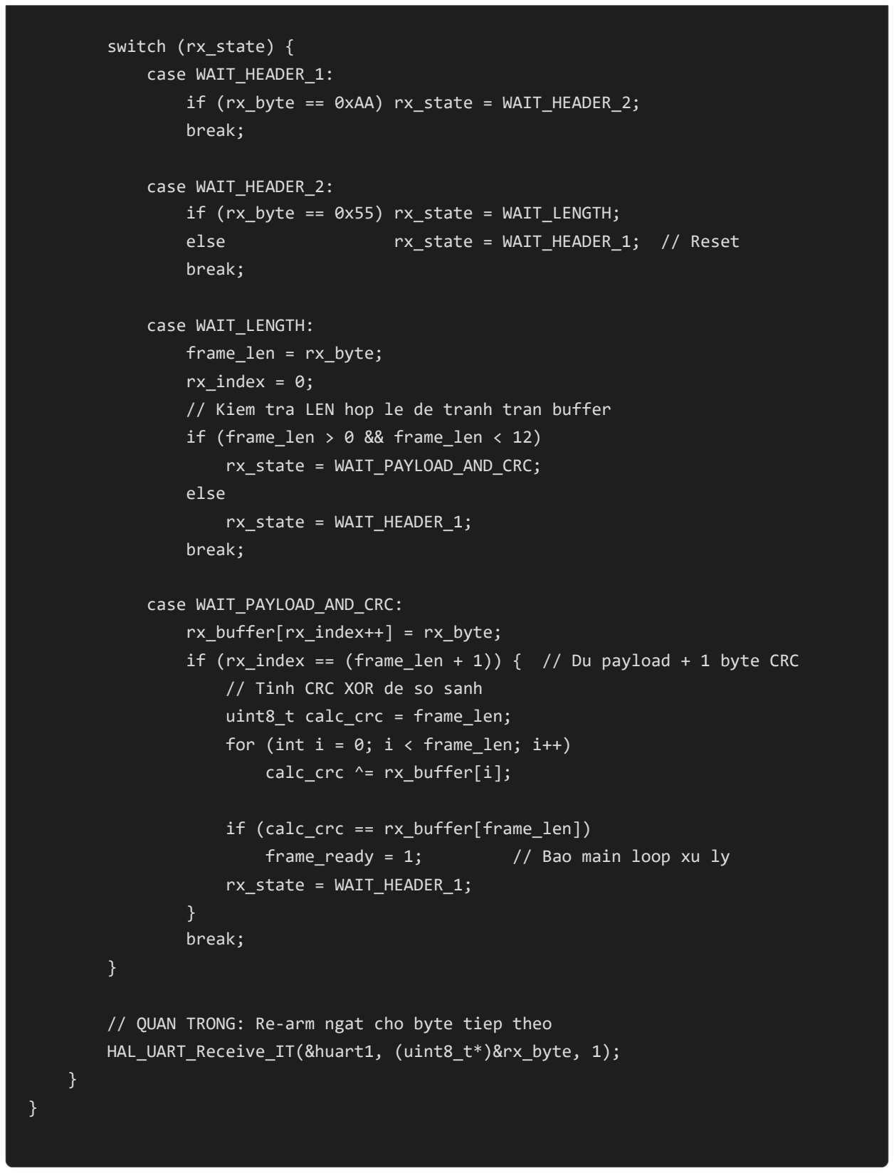
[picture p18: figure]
switch (rx_state) { case WAIT_HEADER_1:; break;; case WAIT_HEADER_2:; else; rx_state = WAIT_HEADER_1; // Reset; case WAIT_LENGTH: frame_len = rx_byte; rx_index = 0;; if (frame_len > 0 && frame_len < 12) rx_state = WAIT_PAYLOAD_AND_CRC;; rx_state = WAIT_HEADER_1; break;; case WAIT_PAYLOAD_AND_CRC: rx_buffer[rx_index++] = rx_byte;; // Tinh CRC XOR de so sanh uint8_t calc_crc = frame_len; for (int i = 0; i < frame_len; i++) calc_crc ^= rx_buffer[i];; if (calc_crc == rx_buffer[frame_len]); frame_ready = 1;; // Bao main loop xu ly; rx_state = WAIT_HEADER_1;; } break;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

if (rx_byte == 0xAA) rx_state = WAIT_HEADER_2;

if (rx_byte == 0x55) rx_state = WAIT_LENGTH;

// Kiem tra LEN hop le de tranh tran buffer

if (rx_index == (frame_len + 1)) { // Du payload + 1 byte CRC

// QUAN TRONG: Re-arm ngat cho byte tiep theo

### 4.1.5. Xử lý lệnh ở vòng lặp chính (không nằm trong ISR)

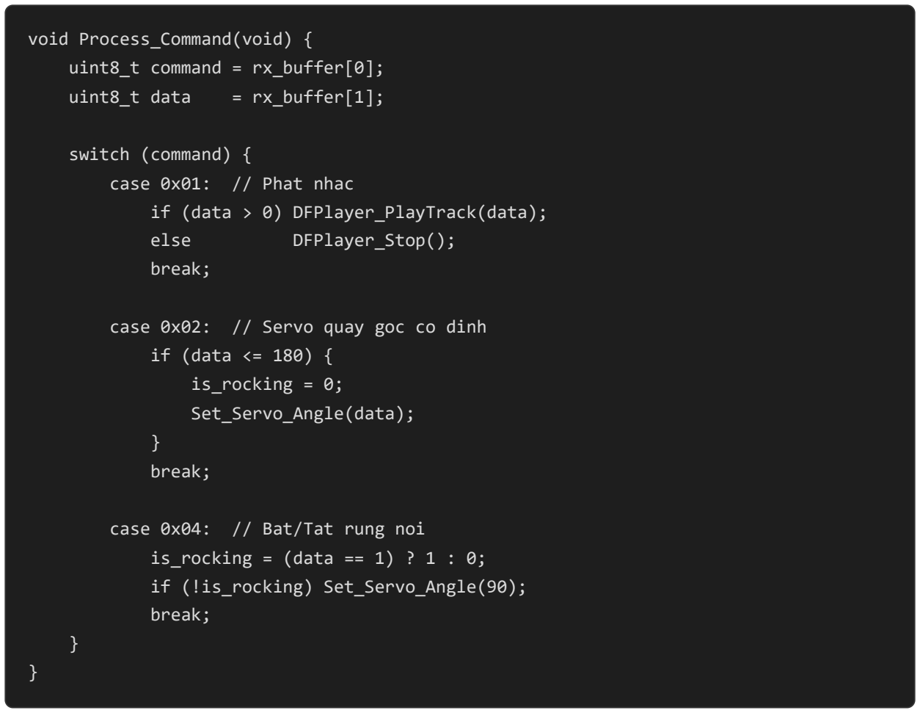
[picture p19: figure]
void Process_Command(void) { uint8_t command = rx_buffer[0];; uint8_t data; = rx_buffer[1];; switch (command) { case 0x01: // Phat nhac if (data > 0) DFPlayer_PlayTrack(data);; else; DFPlayer_Stop();; break;; case 0x02: // Servo quay goc co dinh if (data <= 180) { is_rocking = 0; Set_Servo_Angle(data);; } break;; case 0x04: // Bat/Tat rung noi is_rocking = (data == 1) ? 1 : 0; if (!is_rocking) Set_Servo_Angle(90); break;

Checklist an toàn khi dùng ngắt UART:
Buffer luôn có kiểm tra giới hạn ( frame_len < 12 ) để chống overflow Có cơ chế reset về WAIT_HEADER_1 khi gặp byte sai
Luôn re-arm HAL_UART_Receive_IT() ở cuối callback
Mọi biến dùng chung giữa ISR và main() đều phải khai báo volatile Tuyệt đối không gọi HAL_Delay , printf , logic dài trong callback

## 4.2. Đa nhiệm không cần RTOS — Non-blocking Super Loop

### 4.2.1. Vấn đề của HAL_Delay()

Giả sử ta muốn chạy đồng thời ba tác vụ: đọc DHT22 mỗi 2 giây, rung nôi mỗi 20ms, phản hồi UART ngay lập tức. Nếu viết kiểu blocking:

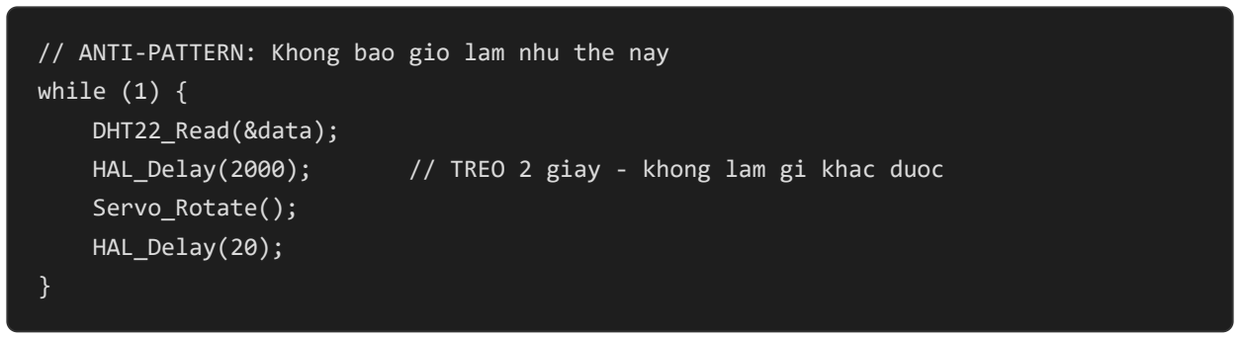
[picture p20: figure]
while (1) { DHT22_Read(&data);; Servo_Rotate(); HAL_Delay(20);

// ANTI-PATTERN: Khong bao gio lam nhu the nay

HAL_Delay(2000); | // TREO 2 giay - khong lam gi khac duoc

Trong 2 giây chờ đó, servo đứng im, UART không phản hồi. Đây là sai thiết kế cơ bản.

### 4.2.2. Mẫu thiết kế Cooperative Scheduling

Hàm HAL_GetTick() trả về số mili giây từ lúc khởi động (chạy bằng SysTick nền, không chặn CPU). Ta biến mỗi tác vụ thành một hàm tự kiểm tra "đã đến giờ mình chạy chưa?":

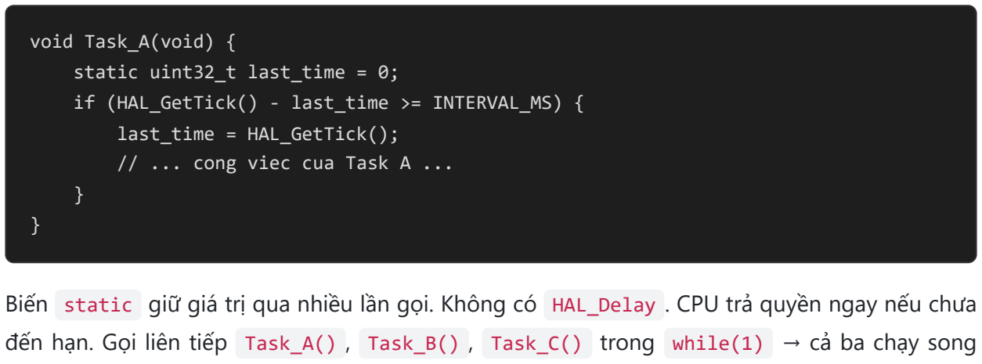
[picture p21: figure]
void Task_A(void) { static uint32_t last_time = 0;; last_time = HAL_GetTick(); // ... cong viec cua Task A ...

if (HAL_GetTick() - last_time >= INTERVAL_MS) {

Biến static giữ giá trị qua nhiều lần gọi. Không có HAL_Delay . CPU trả quyền ngay nếu chưa đến hạn. Gọi liên tiếp Task_A() , Task_B() , Task_C() trong while(1) → cả ba chạy song song ở góc nhìn của người dùng.

### 4.2.3. Case study: Servo_Rocking_Task()

Yêu cầu: Servo quay qua lại giữa 60° và 120° (biên độ an toàn, không lật nôi), mỗi bước 1° cách nhau 20ms cho chuyển động mượt như ru thật, có thể bật/tắt từ ESP32 bất cứ lúc nào.

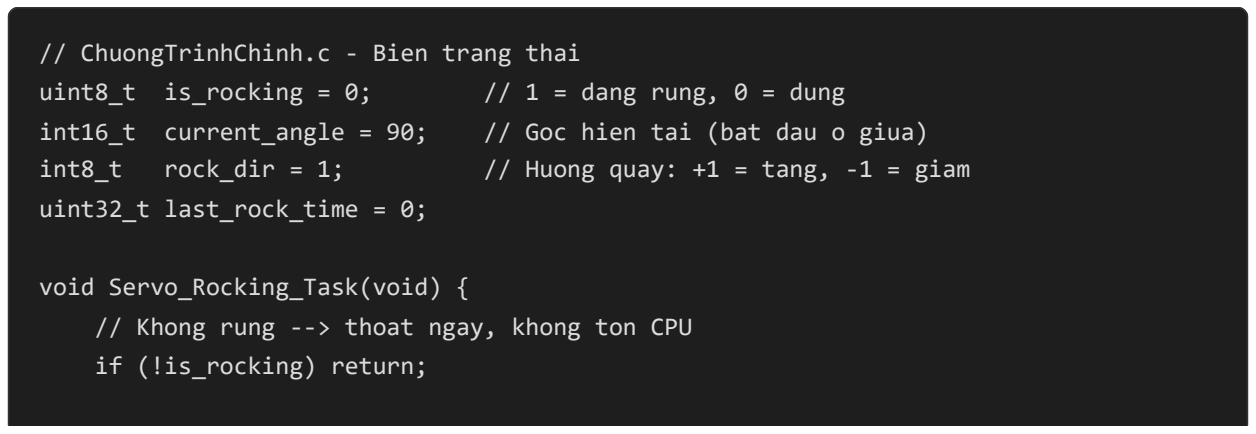
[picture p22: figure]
// ChuongTrinhChinh.c - Bien trang thai; uint32_t last_rock_time = 0;; void Servo_Rocking_Task(void) {; if (!is_rocking) return;

uint8_t is_rocking = 0; | // 1 = dang rung, 0 = dung
int16_t current_angle = 90; | // Goc hien tai (bat dau o giua)
int8_t | rock_dir = 1; | // Huong quay: +1 = tang, -1 = giam

// Khong rung --> thoat ngay, khong ton CPU

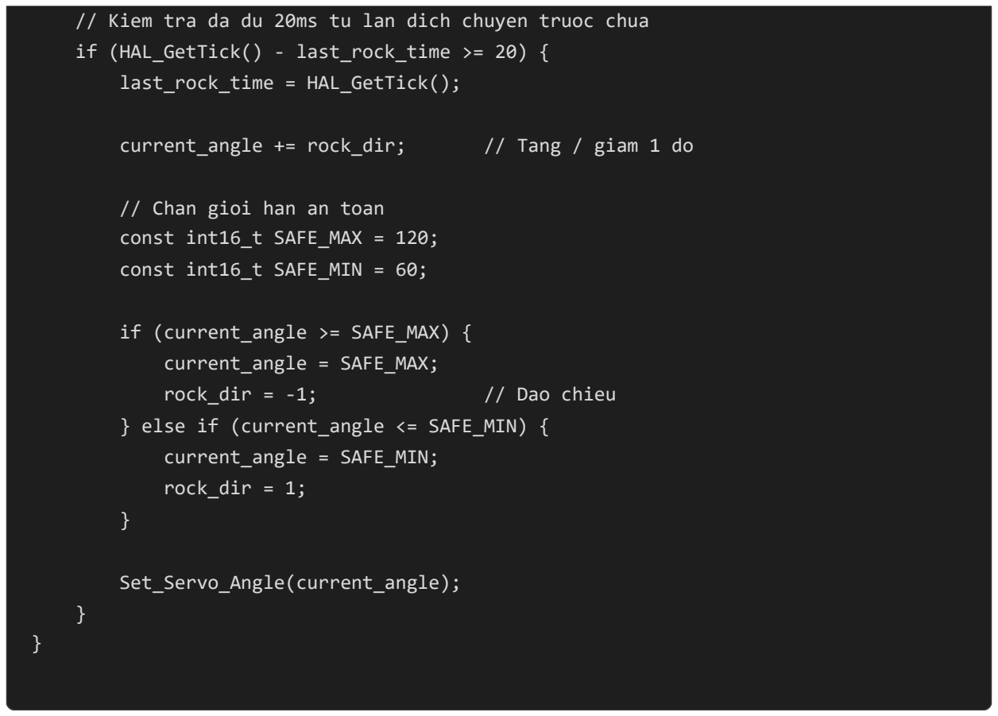
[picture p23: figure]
last_rock_time = HAL_GetTick();; // Chan gioi han an toan const int16_t SAFE_MAX = 120; const int16_t SAFE_MIN = 60;; if (current_angle >= SAFE_MAX) { current_angle = SAFE_MAX;; rock_dir = -1;; // Dao chieu; } else if (current_angle <= SAFE_MIN) { current_angle = SAFE_MIN; rock_dir = 1;; Set_Servo_Angle(current_angle);

// Kiem tra da du 20ms tu lan dich chuyen truoc chua if (HAL_GetTick() - last_rock_time >= 20) {

current_angle += rock_dir; | // Tang / giam 1 do

### 4.2.4. So sánh hai cách tiếp cận

Tiêu chí | Blocking (HAL_Delay) | Non-blocking (HAL_GetTick)
Thời gian phản hồi lệnh mới | Có thể > 1 giây | < 1 ms
CPU khi rảnh | 100% (bận chờ delay) | Gần 0%
Thêm task mới | Phức tạp, phải tính lại timing | Chỉ cần thêm hàm Task_X()
Debug từng bước | Khó (blocking) | Dễ (bước qua được)

### 4.2.5. Mẫu tổng hợp — Super Loop hoàn chỉnh

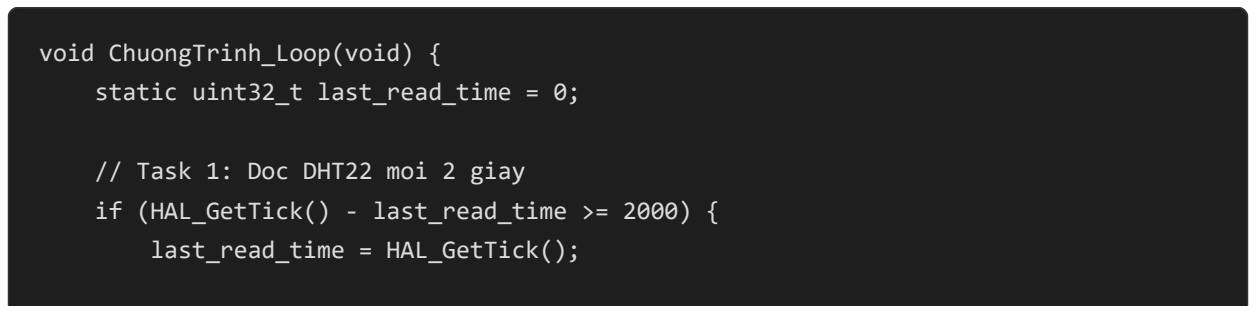
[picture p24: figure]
void ChuongTrinh_Loop(void) { static uint32_t last_read_time = 0;; // Task 1: Doc DHT22 moi 2 giay; last_read_time = HAL_GetTick();

if (HAL_GetTick() - last_read_time >= 2000) {

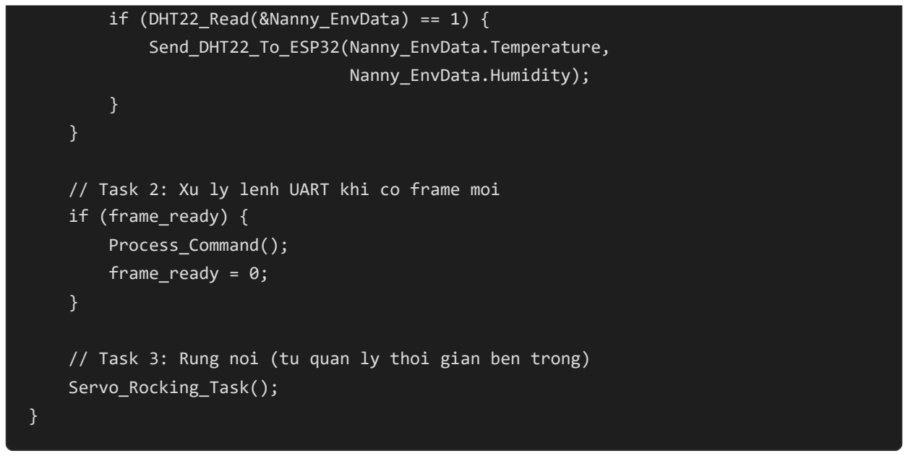
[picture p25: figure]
if (DHT22_Read(&Nanny_EnvData) == 1) { Send_DHT22_To_ESP32(Nanny_EnvData.Temperature, Nanny_EnvData.Humidity);; if (frame_ready) { Process_Command(); frame_ready = 0;; Servo_Rocking_Task();

// Task 2: Xu ly lenh UART khi co frame moi

// Task 3: Rung noi (tu quan ly thoi gian ben trong)

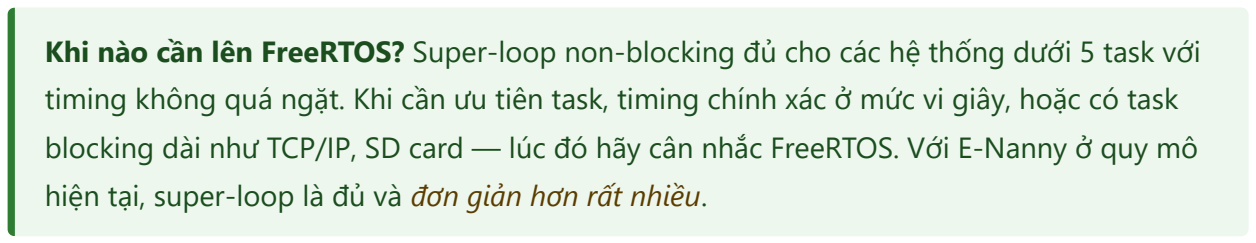
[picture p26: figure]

Khi nào cần lên FreeRTOS? Super-loop non-blocking đủ cho các hệ thống dưới 5 task với timing không quá ngặt. Khi cần ưu tiên task, timing chính xác ở mức vi giây, hoặc có task blocking dài như TCP/IP, SD card — lúc đó hãy cân nhắc FreeRTOS. Với E-Nanny ở quy mô hiện tại, super-loop là đủ và đơn giản hơn rất nhiều.

# CHƯƠNG 5 — HƯỚNG DẪN CÀI ĐẶT & DEBUG

## 5.1. Yêu cầu phần mềm

Công cụ | Phiên bản tối thiểu | Mục đích
STM32CubeIDE | 1.13.0 | IDE chính, có tích hợp CubeMX + GCC + OpenOCD
STM32CubeMX | 6.8.0 (đã bundle trong IDE) | Cấu hình ngoại vi bằng giao diện đồ hoạ
ST-Link Driver | Mới nhất từ st.com | Nạp firmware và debug qua SWD
Arduino IDE hoặc ESP-IDF | 2.2+ / 5.0+ | Lập trình ESP32

Công cụ | Phiên bản tối thiểu | Mục đích
Serial Terminal (PuTTY, Tera Term) | — | Quan sát log UART khi debug

## 5.2. Quy trình cấu hình CubeMX

1. Tạo project mới, chọn MCU STM32F401CCU6 .
2. Tab SYS: Debug → Serial Wire (để nạp và debug được).
3. Tab RCC: HSE → Crystal/Ceramic Resonator (nếu board có thạch anh ngoài, thường là 8MHz hoặc 25MHz). Cấu hình Clock Tree: SYSCLK = 84 MHz, APB1 = 42 MHz (Timer APB1 ×2 = 84 MHz), APB2 = 84 MHz.
4. Cấu hình GPIO PA4: Output Push-Pull, No Pull, Low Speed (chân DHT22).
5. Cấu hình TIM2: Channel 1 → PWM Generation CH1. Prescaler = 47, Counter Period = 19999. Trong PWM Generation: Pulse = 1500 (giá trị khởi đầu 90°). Auto-reload preload = Enable.
6. Cấu hình TIM11: Activated. Prescaler = 83, Counter Period = 65535. Không cần bật ngắt.
7. Cấu hình USART1: Mode Asynchronous, Baudrate 115200, 8N1. Tab NVIC Settings: bật
USART1 global interrupt .
8. Cấu hình USART2: Mode Asynchronous, Baudrate 9600, 8N1.
9. Project Manager → Toolchain: STM32CubeIDE. Code Generator: chọn Generate peripheral initialization as a pair of .c/.h files per peripheral.
10. Nhấn Generate Code.

## 5.3. Các bước chạy dự án lần đầu

1. Copy hai thư mục App/ và App/Libraries/ vào trong Core/ .
2. Vào Project → Properties → C/C++ General → Paths and Symbols → Includes, nhấn

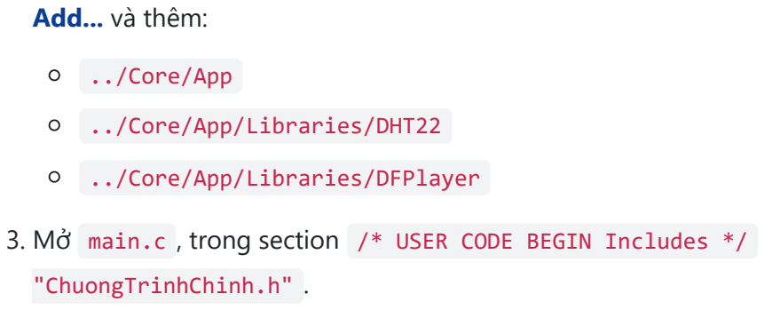
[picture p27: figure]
Add... và thêm:; ../Core/App; ../Core/App/Libraries/DHT22; ../Core/App/Libraries/DFPlayer; "ChuongTrinhChinh.h" .

3. Mở main.c , trong section /* USER CODE BEGIN Includes */ thêm #include

4. Trong main() , sau khối MX_*_Init() , thêm đúng một dòng ChuongTrinh_Init(); .
Trong vòng while(1) thêm ChuongTrinh_Loop(); . Không thêm gì khác.
5. Build (Ctrl+B). Nếu có lỗi "undefined reference" → kiểm tra lại Include Paths. Nếu lỗi "multiple definition" → kiểm tra header guard trong file .h .
6. Kết nối ST-Link, nạp firmware (F11).
7. Mở Serial Terminal trên máy tính, kết nối chân TX-RX của STM32 với USB-TTL, baudrate 115200 để kiểm tra dữ liệu gửi ra.

## 5.4. Các lỗi thường gặp và cách khắc phục

Triệu chứng | Nguyên nhân có thể | Cách khắc phục
DHT22 luôn trả về 0 (đọc lỗi) | Chưa gọi HAL_TIM_Base_Start(&htim11) ; thiếu điện trở kéo lên; đấu nhầm chân | Thêm lệnh start timer trong ChuongTrinh_Init() ; gắn trở 4.7kΩ giữa DATA và VCC; kiểm tra lại sơ đồ
UART nhận được byte nhưng frame không bao giờ ready | Không re-arm HAL_UART_Receive_IT ; CRC tính sai ở ESP32; state machine mắc kẹt | Đảm bảo dòng re-arm ở cuối callback; in log byte nhận được để so sánh; thêm timeout reset về WAIT_HEADER_1 sau 100ms không có byte mới
Servo rung giật, không mượt | Nguồn yếu; chu kỳ PWM sai (không phải 50Hz); có HAL_Delay chen vào trong loop | Cấp nguồn 5V 1A riêng cho servo; kiểm tra lại TIM2 Prescaler=47, Period=19999; rà soát tất cả HAL_Delay trong code
Toàn bộ hệ thống treo sau vài phút | Biến chia sẻ với ISR chưa khai báo volatile ; vòng while chờ không có timeout | Thêm volatile cho rx_byte , frame_ready , rx_state ; kiểm tra mọi while trong driver đều có biến timeout
Nạp code được nhưng không chạy | Chưa cấu hình Clock Tree đúng; HSE không hoạt động | Mở CubeMX, chọn lại HSE crystal, regenerate; hoặc dùng HSI làm clock source để test

## 5.5. Quy trình Debug khoa học

1. Test từng module riêng trước khi tích hợp. Viết một main.c tối giản chỉ để test DHT22, in kết quả qua UART. Sau khi driver chạy ổn mới tích hợp vào hệ thống lớn.
2. Thêm log đường truyền. Trong callback UART, gửi ngược byte vừa nhận ra một UART khác (hoặc qua ITM Trace) để kiểm tra đã nhận đúng chưa.
3. Dùng breakpoint có điều kiện. Đặt breakpoint bên trong Process_Command() với điều kiện command == 0x02 để chỉ dừng khi nhận đúng lệnh servo.
4. Quan sát tín hiệu bằng oscilloscope hoặc logic analyzer. Đây là bước không thể thiếu khi debug giao thức timing-critical như DHT22. Một chiếc logic analyzer USB giá rẻ (như Saleae clone) đủ để xem được 40 bit trả về từ DHT22.
5. Bật Watchdog (IWDG). Sau khi firmware ổn định, bật Independent Watchdog để hệ thống tự reset nếu bị treo. Đây là lớp bảo vệ cuối cùng.

## 5.6. Checklist nghiệm thu cuối cùng

Trước khi bàn giao dự án, hãy tự kiểm tra theo từng mục:

Tổ chức code

main.c dưới 100 dòng logic (không tính phần CubeMX generated) Mỗi module có cặp .c + .h riêng
Tất cả file .h có header guard
Hàm nội bộ đã khai báo static
Biến chia sẻ với ngắt đã khai báo volatile

Tầng phần cứng

Không có HAL_Delay() trong driver timing-critical
Timer µs đã khởi động ( HAL_TIM_Base_Start ) trước khi dùng Có timeout chống treo ở mọi vòng while chờ tín hiệu

Giao tiếp UART

Frame có Header + Length + CRC đầy đủ
State machine có reset khi gặp byte sai Callback ngắt KHÔNG chứa logic dài
Có re-arm HAL_UART_Receive_IT cuối callback

Buffer có kiểm tra giới hạn để chống overflow

Logic ứng dụng

Mọi task định kỳ dùng HAL_GetTick() , không HAL_Delay()
Biến trạng thái có giá trị khởi tạo rõ ràng
Giá trị giới hạn an toàn (góc servo 60-120) có #define hoặc const Đã test từng module riêng trước khi tích hợp

## LỜI KẾT

Lập trình embedded chuyên nghiệp không phải là viết code hoạt động được, mà là viết code có thể đọc hiểu được sau 6 tháng quay lại, tái sử dụng được cho dự án khác, mở rộng được mà không phá code cũ, và debug được khi có lỗi production.
Kiến trúc module, máy trạng thái UART và tư duy non-blocking mà bạn vừa học trong tài liệu này chính là nền móng cho tất cả những điều đó. Hãy áp dụng vào dự án E-Nanny ngay từ hôm nay, và bạn sẽ thấy sự khác biệt rõ rệt khi chuyển sang dự án tiếp theo.

Tài liệu biên soạn cho dự án E-Nanny – Smart Baby Monitor
STM32F401CCU6 + ESP32 | Phiên bản 1.0 | 2026

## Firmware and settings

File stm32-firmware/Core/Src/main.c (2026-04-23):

#include "main.h"
#include "ChuongTrinhChinh.h"
#include "string.h"

// ================== KHAI BAO BIEN NGOAI VI ==================
TIM_HandleTypeDef htim2;
TIM_HandleTypeDef htim11;
UART_HandleTypeDef huart1;
UART_HandleTypeDef huart2;

// ================== KHAI BAO HAM ==================
void SystemClock_Config(void);
static void MX_GPIO_Init(void);
static void MX_TIM2_Init(void);
static void MX_TIM11_Init(void);
static void MX_USART1_UART_Init(void);
static void MX_USART2_UART_Init(void);
void Error_Handler(void);

// ================== CHUONG TRINH CHINH ==================
int main(void) {
    HAL_Init();
    SystemClock_Config();

    MX_GPIO_Init();
    MX_TIM11_Init();
    MX_TIM2_Init();
    MX_USART1_UART_Init();
    MX_USART2_UART_Init();

    // Chuyen toan bo logic khoi tao ung dung vao day
    ChuongTrinh_Init();

    while (1) {
        // Vong lap chinh cua ung dung
        ChuongTrinh_Loop();
    }
}

// ================== CAU HINH XUNG NHIP 84MHz ==================
void SystemClock_Config(void) {
    RCC_OscInitTypeDef RCC_OscInitStruct = {0};
    RCC_ClkInitTypeDef RCC_ClkInitStruct = {0};

    __HAL_RCC_PWR_CLK_ENABLE();
    __HAL_PWR_VOLTAGESCALING_CONFIG(PWR_REGULATOR_VOLTAGE_SCALE2);

    // Cau hinh dung thach anh ngoai HSE 25MHz
    RCC_OscInitStruct.OscillatorType = RCC_OSCILLATORTYPE_HSE;
    RCC_OscInitStruct.HSEState = RCC_HSE_ON;
    RCC_OscInitStruct.PLL.PLLState = RCC_PLL_ON;
    RCC_OscInitStruct.PLL.PLLSource = RCC_PLLSOURCE_HSE;
    RCC_OscInitStruct.PLL.PLLM = 25;
    RCC_OscInitStruct.PLL.PLLN = 168;
    RCC_OscInitStruct.PLL.PLLP = RCC_PLLP_DIV2;
    RCC_OscInitStruct.PLL.PLLQ = 4;
    if (HAL_RCC_OscConfig(&RCC_OscInitStruct) != HAL_OK) Error_Handler();

    // Chia clock cho cac bus
    RCC_ClkInitStruct.ClockType = RCC_CLOCKTYPE_HCLK | RCC_CLOCKTYPE_SYSCLK | RCC_CLOCKTYPE_PCLK1 | RCC_CLOCKTYPE_PCLK2;
    RCC_ClkInitStruct.SYSCLKSource = RCC_SYSCLKSOURCE_PLLCLK;
    RCC_ClkInitStruct.AHBCLKDivider = RCC_SYSCLK_DIV1;
    RCC_ClkInitStruct.APB1CLKDivider = RCC_HCLK_DIV2;
    RCC_ClkInitStruct.APB2CLKDivider = RCC_HCLK_DIV1;
    if (HAL_RCC_ClockConfig(&RCC_ClkInitStruct, FLASH_LATENCY_2) != HAL_OK) Error_Handler();
}

// ================== KHOI TAO GPIO CO BAN ==================
static void MX_GPIO_Init(void) {
    __HAL_RCC_GPIOA_CLK_ENABLE(); // Cap xung clock cho PORTA
}

// ================== KHOI TAO TIM11 ==================
static void MX_TIM11_Init(void) {
    __HAL_RCC_TIM11_CLK_ENABLE();
    htim11.Instance = TIM11;
    htim11.Init.Prescaler = 84 - 1;       // Dua ve 1ms
    htim11.Init.CounterMode = TIM_COUNTERMODE_UP;
    htim11.Init.Period = 65535;           // Max
    htim11.Init.ClockDivision = TIM_CLOCKDIVISION_DIV1;
    if (HAL_TIM_Base_Init(&htim11) != HAL_OK) Error_Handler();
}

// ================== KHOI TAO TIM2 PWM Servo 50Hz ==================
static void MX_TIM2_Init(void) {
    TIM_ClockConfigTypeDef sClockSourceConfig = {0};
    TIM_MasterConfigTypeDef sMasterConfig = {0};
    TIM_OC_InitTypeDef sConfigOC = {0};
    GPIO_InitTypeDef GPIO_InitStruct = {0};

    __HAL_RCC_TIM2_CLK_ENABLE(); // Cap clock cho TIM2

    // Cau hinh chan PA0 lam PWM CH1
    GPIO_InitStruct.Pin = GPIO_PIN_0;
    GPIO_InitStruct.Mode = GPIO_MODE_AF_PP;
    GPIO_InitStruct.Pull = GPIO_NOPULL;
    GPIO_InitStruct.Speed = GPIO_SPEED_FREQ_LOW;
    GPIO_InitStruct.Alternate = GPIO_AF1_TIM2;
    HAL_GPIO_Init(GPIOA, &GPIO_InitStruct);

    // Cau hinh TIM2 tao xung 50Hz
    htim2.Instance = TIM2;
    htim2.Init.Prescaler = 84 - 1;
    htim2.Init.CounterMode = TIM_COUNTERMODE_UP;
    htim2.Init.Period = 20000 - 1;
    htim2.Init.ClockDivision = TIM_CLOCKDIVISION_DIV1;
    if (HAL_TIM_Base_Init(&htim2) != HAL_OK) Error_Handler();

    sClockSourceConfig.ClockSource = TIM_CLOCKSOURCE_INTERNAL;
    if (HAL_TIM_ConfigClockSource(&htim2, &sClockSourceConfig) != HAL_OK) Error_Handler();
    if (HAL_TIM_PWM_Init(&htim2) != HAL_OK) Error_Handler();

    sMasterConfig.MasterOutputTrigger = TIM_TRGO_RESET;
    sMasterConfig.MasterSlaveMode = TIM_MASTERSLAVEMODE_DISABLE;
    if (HAL_TIMEx_MasterConfigSynchronization(&htim2, &sMasterConfig) != HAL_OK) Error_Handler();

    sConfigOC.OCMode = TIM_OCMODE_PWM1;
    sConfigOC.Pulse = 0;
    sConfigOC.OCPolarity = TIM_OCPOLARITY_HIGH;
    sConfigOC.OCFastMode = TIM_OCFAST_DISABLE;
    if (HAL_TIM_PWM_ConfigChannel(&htim2, &sConfigOC, TIM_CHANNEL_1) != HAL_OK) Error_Handler();
}

// ================== KHOI TAO USART1 ==================
static void MX_USART1_UART_Init(void) {
    GPIO_InitTypeDef GPIO_InitStruct = {0};

    __HAL_RCC_USART1_CLK_ENABLE();

    // Cau hinh chan PA9 TX va PA10 RX
    GPIO_InitStruct.Pin = GPIO_PIN_9 | GPIO_PIN_10;
    GPIO_InitStruct.Mode = GPIO_MODE_AF_PP;
    GPIO_InitStruct.Pull = GPIO_NOPULL;
    GPIO_InitStruct.Speed = GPIO_SPEED_FREQ_VERY_HIGH;
    GPIO_InitStruct.Alternate = GPIO_AF7_USART1;
    HAL_GPIO_Init(GPIOA, &GPIO_InitStruct);

    // Cau hinh USART1 Baudrate 115200
    huart1.Instance = USART1;
    huart1.Init.BaudRate = 115200;
    huart1.Init.WordLength = UART_WORDLENGTH_8B;
    huart1.Init.StopBits = UART_STOPBITS_1;
    huart1.Init.Parity = UART_PARITY_NONE;
    huart1.Init.Mode = UART_MODE_TX_RX;
    huart1.Init.HwFlowCtl = UART_HWCONTROL_NONE;
    huart1.Init.OverSampling = UART_OVERSAMPLING_16;
    if (HAL_UART_Init(&huart1) != HAL_OK) Error_Handler();

    // Bat ngat NVIC cho USART1
    HAL_NVIC_SetPriority(USART1_IRQn, 1, 0);
    HAL_NVIC_EnableIRQ(USART1_IRQn);
}

// ================== KHOI TAO USART2 ==================
static void MX_USART2_UART_Init(void) {
    GPIO_InitTypeDef GPIO_InitStruct = {0};

    __HAL_RCC_USART2_CLK_ENABLE();

    // Cau hinh chan PA2 TX va PA3 RX
    GPIO_InitStruct.Pin = GPIO_PIN_2 | GPIO_PIN_3;
    GPIO_InitStruct.Mode = GPIO_MODE_AF_PP;
    GPIO_InitStruct.Pull = GPIO_NOPULL;
    GPIO_InitStruct.Speed = GPIO_SPEED_FREQ_VERY_HIGH;
    GPIO_InitStruct.Alternate = GPIO_AF7_USART2;
    HAL_GPIO_Init(GPIOA, &GPIO_InitStruct);

    // Cau hinh USART2 Baudrate 9600 cho mach MP3
    huart2.Instance = USART2;
    huart2.Init.BaudRate = 9600;
    huart2.Init.WordLength = UART_WORDLENGTH_8B;
    huart2.Init.StopBits = UART_STOPBITS_1;
    huart2.Init.Parity = UART_PARITY_NONE;
    huart2.Init.Mode = UART_MODE_TX_RX;
    huart2.Init.HwFlowCtl = UART_HWCONTROL_NONE;
    huart2.Init.OverSampling = UART_OVERSAMPLING_16;
    if (HAL_UART_Init(&huart2) != HAL_OK) Error_Handler();
}

// ================== CAC HAM NGAT HE THONG COT LOI ==================

// Ham ngat phan cung he thong tro toi bat buoc phai co de chay ngat USART1
void USART1_IRQHandler(void) {
    HAL_UART_IRQHandler(&huart1);
}

// Ham ngat nhip tim SysTick
void SysTick_Handler(void) {
    HAL_IncTick();
}

// Ham ngat bat loi phan cung nghiem trong
void HardFault_Handler(void) {
    __disable_irq();
    while (1) {}
}

void Error_Handler(void) {
    __disable_irq();
    while (1) {}
}

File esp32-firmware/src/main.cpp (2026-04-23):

#include <Arduino.h>
#include "CloudClient.h"
#include "CameraModule.h"
#include "Stm32Controller.h"
#include "AudioMic.h"
#include "AiEngine.h"

int cry_detected_count = 0;
int silence_count = 0; 
const int REQUIRE_CRY_COUNT = 2;

void setup() {
  Serial.begin(115200);
  Serial.println("Khoi dong he thong E-Nanny...");

  initStm32UART();
  setupCamera();
  audio_mic_init();
  setupCloud();

  Serial.println("E-Nanny System Ready!");
}

void loop() {
  cloudLoop(); // Xu ly giu ket noi mang va MQTT
  
//  checkSerialCommands();
  processIncomingUART(); // Doc du lieu UART tu STM32

  // Chay module AI nhan dien tieng khoc
  if (is_buffer_ready) {
    float current_score = run_cry_detection();
    
    if (current_score >= 0.5) {
      cry_detected_count++;
      silence_count = 0; // Reset bo dem im lang
      if (cry_detected_count >= REQUIRE_CRY_COUNT) {
         Serial.printf("=> PHAT HIEN TIENG KHOC! Score: %.2f\n", current_score);
         sendCommandToSTM32(0x04, 1); // Bat noi
         sendCommandToSTM32(0x01, 1); // Bat nhac
         updateBabyStatus("Em be dang khoc"); // API hien thi tren App
         cry_detected_count = 0; 
      }
    } else {
      cry_detected_count = 0; 
      silence_count++;
      if (silence_count >= 10) { // Neu im lang mot luc lau 
         updateBabyStatus("Em be ngu ngoan");
      }
    }
    is_buffer_ready = false;
  }
  
  delay(10); 
}

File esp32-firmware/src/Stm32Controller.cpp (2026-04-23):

#include "Stm32Controller.h"
#include "CloudClient.h"

enum RX_STATE { WAIT_HEADER_1, WAIT_HEADER_2, WAIT_LENGTH, WAIT_PAYLOAD_AND_CRC };
RX_STATE rx_state = WAIT_HEADER_1;

uint8_t rx_buffer[16];
uint8_t rx_index = 0;
uint8_t frame_len_rx = 0;

void initStm32UART() {
  Serial1.begin(115200, SERIAL_8N1, RX_PIN_TO_STM32, TX_PIN_TO_STM32);
}

void sendCommandToSTM32(uint8_t command, uint8_t data) {
  uint8_t frame_len = 2; 
  uint8_t crc = frame_len ^ command ^ data; 
  uint8_t tx_buffer[6] = {0xAA, 0x55, frame_len, command, data, crc};
  Serial1.write(tx_buffer, 6);
}

void checkSerialCommands() {
  if (Serial.available() > 0) {
    String input = Serial.readStringUntil('\n');
    input.trim();
    if (input == "batnoi") {
      Serial.println("=> APP: Bat noi");
      sendCommandToSTM32(0x04, 1);
    } 
    else if (input == "tat noi") {
      Serial.println("=> APP: Tat noi");
      sendCommandToSTM32(0x04, 0); 
    }
    else if (input == "bat loa") {
      Serial.println("=> APP: Bat loa");
      sendCommandToSTM32(0x01, 1);
    }
    else if (input == "tat loa") {
      Serial.println("=> APP: Tat loa");
      sendCommandToSTM32(0x01, 0);
    }
  }
}

void processIncomingUART() {
  while (Serial1.available() > 0) {
    uint8_t rx_byte = Serial1.read();
    
    switch (rx_state) {
      case WAIT_HEADER_1: if (rx_byte == 0xAA) rx_state = WAIT_HEADER_2; break;
      case WAIT_HEADER_2: if (rx_byte == 0x55) rx_state = WAIT_LENGTH; else rx_state = WAIT_HEADER_1; break;
      case WAIT_LENGTH:
        frame_len_rx = rx_byte; rx_index = 0;
        if (frame_len_rx > 0 && frame_len_rx < 12) rx_state = WAIT_PAYLOAD_AND_CRC;
        else rx_state = WAIT_HEADER_1;
        break;
        
      case WAIT_PAYLOAD_AND_CRC:
        rx_buffer[rx_index++] = rx_byte;
        if (rx_index == (frame_len_rx + 1)) { 
          uint8_t calc_crc = frame_len_rx;
          for (int i = 0; i < frame_len_rx; i++) calc_crc ^= rx_buffer[i];
          
          if (calc_crc == rx_buffer[frame_len_rx]) {
            uint8_t command = rx_buffer[0];
            if (command == 0x03) { // Lenh Nhiet do do am
              uint8_t temp = rx_buffer[1];
              uint8_t hum = rx_buffer[2];
              Serial.printf("=> SENSOR: Nhiet do = %d C, Do am = %d %%\n", temp, hum);
              sendTelemetry(temp, hum); // Goi ham tu CloudClient
            }
          } else {
             Serial.println("=> LOI: Sai ma CRC tu STM32!");
          }
          rx_state = WAIT_HEADER_1;
        }
        break;
    }
  }
}

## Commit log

2026-04-23 add stm32 and esp32 firmware
2026-04-23 add stm32 firmware
2026-04-24 add 3D solidworks
    [11_20mm pin.step.SLDPRT, 1x20 Male Pin Header.STEP.SLDPRT, BoardDong7x9.SLDPRT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]
2026-04-25 add solidwork picture and video
    [BoardDong7x9.SLDPRT, DeHop7x9.SLDDRW, DeHop7x9.SLDPRT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]
2026-04-26 add pin header
    [1x10.SLDPRT, 1x7.SLDPRT, pin header female 2.54mm_0.1in.SLDPRT]
2026-04-26 add female pin

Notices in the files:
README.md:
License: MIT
